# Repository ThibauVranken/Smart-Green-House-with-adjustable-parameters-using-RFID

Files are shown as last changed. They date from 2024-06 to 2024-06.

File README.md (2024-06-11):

# Smart-Green-House-with-adjustable-parameters-using-RFID

In this project, you will see how to make your own smart greenhouse with customisable parameters using RFID. The measured sensor values are nicely displayed in a Grafana dashboard via a Grafana server.  You can use this in the industry, for example, to reduce costs in terms of actuator energy or to get a better picture of the situation your plants are in. This way, the plants will always have the ideal environment so they grow faster and healthier.

Folder ‘Documentation + tutorial’:
All hardware and software are in the document ‘Documentatie Serre’ and the explanation to set up a Grafana server is in the document ‘Grafana server’.

Folder ‘Code’:
The code for the ESP32 and the RaspberryPi (MQTT - InfluxDB bridge) are both in this folder.

Folder ‘PCB’:
Here you will find the electronic schematic and pcb design. For more explanation of the circuits, please see ‘Documentatie Serre’.

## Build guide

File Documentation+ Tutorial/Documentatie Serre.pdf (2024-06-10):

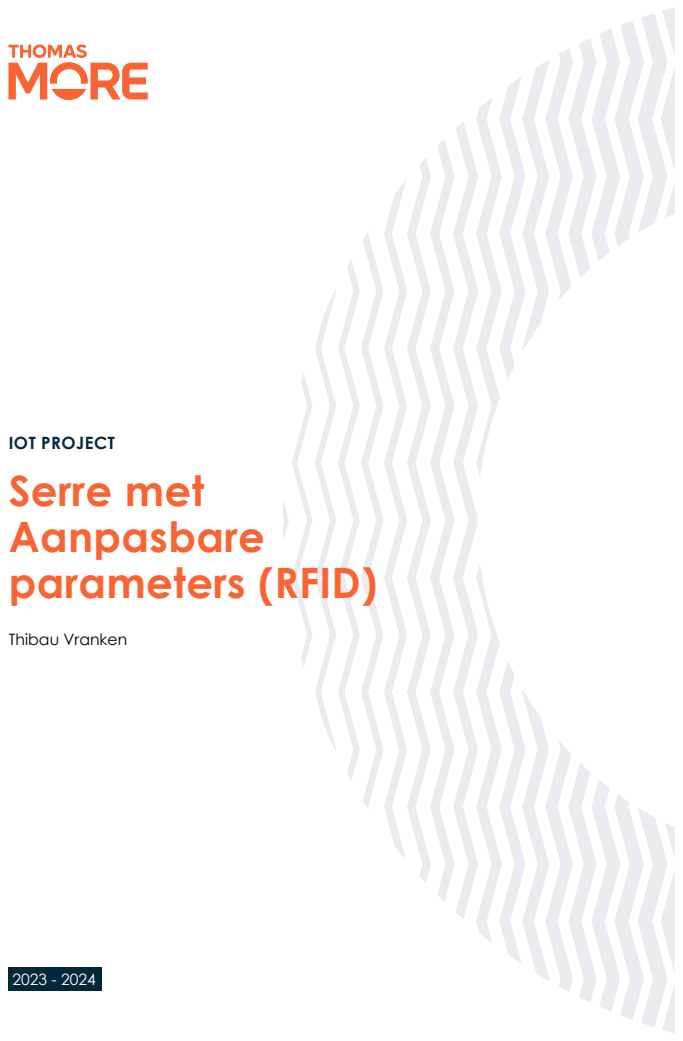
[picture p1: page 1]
IoT project Thibau Vranken; IOT PROJECT Serre met Aanpasbare parameters (RFID); Thibau Vranken

Dit is de koptekst in stijl ‘Koptekst’

# Inhoud

### 1. PROJECTBESCHRIJVING ____________________________________________________________4

### 2. HARDWARE _______________________________________________________________________5

2.1. Microcontrollers _________________________________________________________________5
2.1.1. ESP32 _____________________________________________________________________5
2.1.2. RaspberryPi 4B ______________________________________________________________5
2.2. PCB Hardware __________________________________________________________________6
2.2.1. 2x 5V relay’s_________________________________________________________________6
2.2.2. 3x PC817 optocouplers ________________________________________________________6
2.2.3. 5x BC547B transistors _________________________________________________________6
2.2.4. Schroefterminals _____________________________________________________________7
2.2.5. 5x rode Feedback LED_________________________________________________________7
2.2.6. Weerstanden ________________________________________________________________8
2.2.7. Pinheaders __________________________________________________________________8
2.3. Sensors en Modules ______________________________________________________________9
2.3.1. DHT11 _____________________________________________________________________9
2.3.2. LDR module _________________________________________________________________9
2.3.3. Bodemvochtigheidssensor ______________________________________________________9
2.3.4. DS18B20 sensor ____________________________________________________________10
2.3.5. RFID module _______________________________________________________________10
2.3.6. HC SR04 Ultrasone sensor ____________________________________________________ 11
2.4. Actuatoren ____________________________________________________________________ 11
2.4.1. 2x 12V ventilatoren___________________________________________________________ 11
2.4.2. Waterpompje _______________________________________________________________12
2.4.3. Oude soldeerbout____________________________________________________________12
2.4.4. Lamp _____________________________________________________________________12
2.4.5. Oude visbak (Serre) __________________________________________________________13

### 3. PCB _____________________________________________________________________________13

3.1. Schema_______________________________________________________________________13
3.1.1. Verbindingen sensors_________________________________________________________14
3.1.2. Schakelingen Actuatoren ______________________________________________________14
3.2. PCB design____________________________________________________________________16

### 4. CODE____________________________________________________________________________17

4.1. Code ESP32 ___________________________________________________________________17
4.1.1. Volledige code ______________________________________________________________17
4.1.2. Code uitgelegd ______________________________________________________________17
4.2. Code RaspberryPi ______________________________________________________________29
4.2.1. Volledige code ______________________________________________________________29
4.2.2. Code Uitgelegd______________________________________________________________29

### 5. GRAFANA SERVER ________________________________________________________________33

5.1. MQTT communicatie_____________________________________________________________33
5.1.1. Mosquitto installeren _________________________________________________________33

5.1.2. Configuratie bestand aanpassen ________________________________________________33
5.1.3. Code maken en kijken of de communicatie goed gebeurt _____________________________33
5.2. Server Setup___________________________________________________________________34
5.2.1. Installeer InfluxDB ___________________________________________________________34
5.2.2. Maak een database aan_______________________________________________________34
5.2.3. Controleer of de data aankomt in de database _____________________________________35
5.3. InfluxDB connecteren met Grafana voor visualisatie ____________________________________35
5.3.1. Zoek je Grafana server________________________________________________________35
5.3.2. Log in in Grafana ____________________________________________________________35
5.3.3. Maak een connectie met je InfluxDB database _____________________________________36
5.4. Data Visualisatie ________________________________________________________________38

### 6. DATASHEETS _____________________________________________________________________38

6.1. ESP 32 _______________________________________________________________________38
6.2. RaspberryPi ___________________________________________________________________38
6.3. BC547B Transistor ______________________________________________________________38
6.4. PC 817 optocoupler _____________________________________________________________38
6.5. 5V relay_______________________________________________________________________39
6.6. Feedback LED’s ________________________________________________________________39

# 1. Projectbeschrijving

Het project is een slimme serre die zichzelf regelt qua omgevingstemperatuur, bodem- en luchtvochtigheid en licht.

Deze waarden worden gemonitord (actuatoren worden op het juiste moment aangestuurd) door een ESP32 die de waarden doorstuurt naar een RaspberryPi waarna deze de waarden doorstuurt naar de InfluxDB database zodat we op Grafana een mooi overzicht krijgen van de geschiedenis van de waarden.

We kunnen de parameters voor alle gegevens aanpassen door RFID tags te scannen die elk vaste parameters hebben. Bijvoorbeeld: Als we de blauwe RFID tag scannen wordt de maximum temperatuur gezet op 25°C (als de temperatuur hoger is dan 25°C dan wordt er aan ventilator aangestuurd), als we dan de witte tag scannen wordt de maximale temperatuur gezet op bijvoorbeeld 20°C (zo gaat de ventilator sneller aan om de temperatuur onder 20°C te houden).

# 2. Hardware

### 2.1. Microcontrollers

### 2.1.1. ESP32

De ESP32 regelt de hele serre. Het meet de temperatuur van de omgeving en bodem, het meet de lucht-en bodemvochtigheid, of er veel licht is in de omgeving en hoeveel water in het waterreservoir zit (alle sensoren hiervoor worden vermeldt in ‘Sensors en Actuatoren’). Het houdt ook rekening met welke RFID tag voor het laatst gescand geweest is zodat alles op het juiste moment wordt aangestuurd.

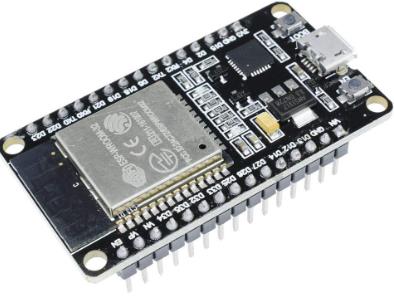
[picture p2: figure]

### 2.1.2. RaspberryPi 4B

De RaspberryPi ontvangt alle waarden van de ESP32 via MQTT en stuurt deze naar de InfluxDB Database. Hierdoor kunnen we mooi en overzichtelijk de geschiedenis van de waarden zien.

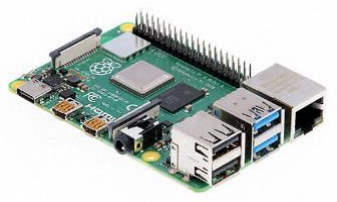
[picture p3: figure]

### 2.2. PCB Hardware

2.2.1. 2x 5V relay’s

Deze zorgen ervoor dat je hoge voltages kan schakelen (240V). Dit is handig voor de lamp (als het te donker is) en de verwarming (als het te koud is).

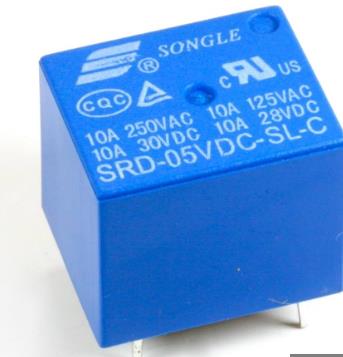
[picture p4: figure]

2.2.2. 3x PC817 optocouplers

Met de PC817 kan je veilig schakelingen galvanisch scheiden doordat het een transistor is met een lichgevoelige basis. De LED die de basis van de transistor moet schakelen wordt gecontroleerd door de ESP32. Op deze manier blijven de stroomkringen van de actuatoren en de ESP32 mooi gescheiden. (Voor toepassing, zie Schakelingen Actuatoren, Lage Voltages)

2.2.3. 5x BC547B transistors

Om de relay en de PC817 te kunnen schakelen heb ik de BC547B transistor gebruikt. Ze worden wel anders gebruikt naargelang de voltage die geschakeld moet worden (zie Schakelingen Actuatoren).

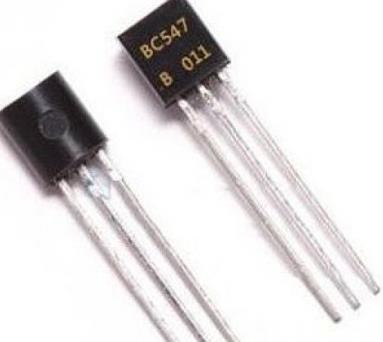
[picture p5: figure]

### 2.2.4. Schroefterminals

2.2.4.1. 2 Schroefterminals

Om de actuatoren en de voedingen voor de actuatoren niet definitief te monteren aan het PCB heb ik 10 keer 2 schroefterminals gebruikt. Zo kun je ook makkelijk veranderingen doen aan de voedingen/actuatoren.

2.2.4.2. 3 Schroefterminal

Om de DS18B20 sensor (niet definitief) te kunnen monteren heb ik een 3 schroefterminal gebruikt.

2.2.5. 5x rode Feedback LED

Om duidelijk te kunnen zien welke actuatoren aan zijn (welke schakeling geschakeld is), heb ik in elke schakeling een rode feedback LED geplaatst zodat je aan de LED kunt zien wat ‘aan’ is en wat ‘uit’ is.

### 2.2.6. Weerstanden

Weerstanden heb ik gebruikt om de juiste stroom/voltage vereisten te krijgen voor elke schakeling (zie PCB Design voor juiste waarden).

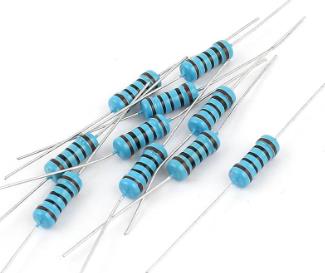
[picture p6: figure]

### 2.2.7. Pinheaders

### 2.2.7.1. Male headers

Om de sensoren te kunnen verbinden met het PCB heb ik male headers gebruikt om zo via jumpercables de sensor op de juiste plaats te krijgen.

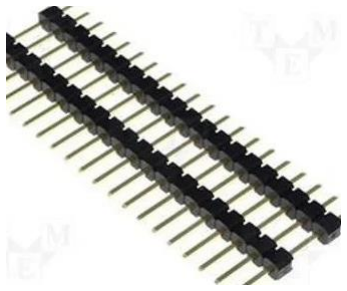
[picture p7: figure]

### 2.2.7.2. Female Headers

Om modules snel te kunnen vervangen en niet definitief aan het PCB te moeten hangen heb ik female headers gebruikt.

### 2.3. Sensors en Modules

### 2.3.1. DHT11

Om de omgevingstemperatuur en luchtvochtigheid te kunnen meten en monitoren heb ik de DHT11 sensor gebruikt.

### 2.3.2. LDR module

Om het licht in de omgeving te meten heb ik de LDR module gebruikt.

### 2.3.3. Bodemvochtigheidssensor

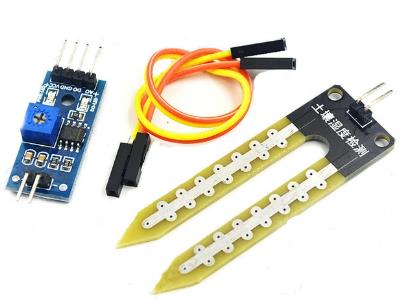
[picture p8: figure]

Om de bodemvochtigheid te kunnen meten heb ik deze bodemvochtigheidssensor gebruikt.

### 2.3.4. DS18B20 sensor

Met de DS18B20 sensor kan ik de bodemtemperatuur meten.

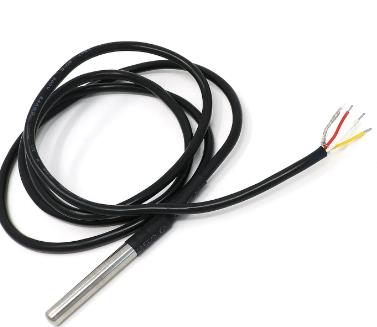
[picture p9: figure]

### 2.3.5. RFID module

Om de parameters aan te kunnen passen naargelang het gewas/plant er in de serre staat kan je je RFID tags scannen op de RFID module. Elke tag heeft vaste vooraf ingestelde parameters (je kan deze aanpassen in je code). Zo kun je snel en makkelijk het systeem van je serre veranderen.

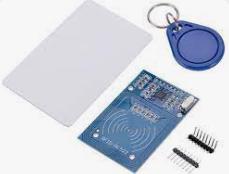
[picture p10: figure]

### 2.3.6. HC SR04 Ultrasone sensor

De HC SR04 sensor kan zeer gedetailleerd afstanden meten. Ik heb deze boven het wateroppervlak van het waterreservoir geplaatst zodat je de inhoud van het waterreservoir kan meten en monitoren.

### 2.4. Actuatoren

2.4.1. 2x 12V ventilatoren

Om de luchtvochtigheid en temperatuur te regelen van de serre heb ik 2 ventilatoren gebruikt. Beide heb ik ze in het plafond van de serre geplaatst. De ene ventilator heb ik zo gemonteerd zodat deze lucht in de serre blaast voor als het te warm is, en de andere heb ik zo gemonteerd zodat deze lucht uit de serre haalt zodat de lucht kan opdrogen voor als deze te nat is.

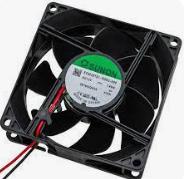
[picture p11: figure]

### 2.4.2. Waterpompje

Om water te kunnen geven aan de planten als de bodem te droog is, heb je natuurlijk een waterpompje nodig. Ik heb daarvoor deze gebruikt:

### 2.4.3. Oude soldeerbout

Als verwarmingselement heb ik een oude soldeerbout gebruikt die ik nog thuis had liggen. Deze heb ik ook door het plafond naar binnen gehangen zodat de warmte mooi verdeeld word in de serre.

### 2.4.4. Lamp

Als het te donker is moet er natuurlijk licht gemaakt worden. Hiervoor heb ik een gewone lamp gebruikt.

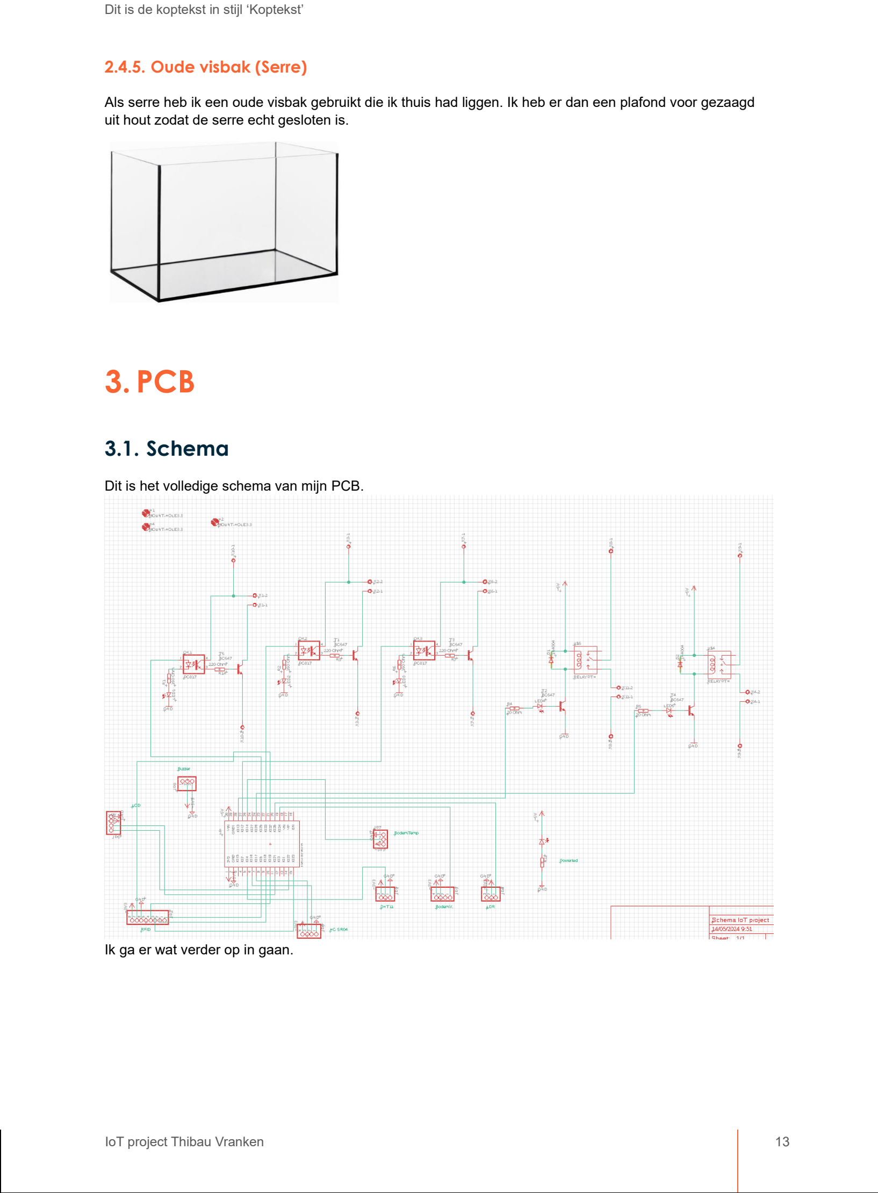
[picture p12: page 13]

### 2.4.5. Oude visbak (Serre)

Als serre heb ik een oude visbak gebruikt die ik thuis had liggen. Ik heb er dan een plafond voor gezaagd uit hout zodat de serre echt gesloten is.

# 3. PCB

### 3.1. Schema

Dit is het volledige schema van mijn PCB.

Ik ga er wat verder op in gaan.

### 3.1.1. Verbindingen sensors

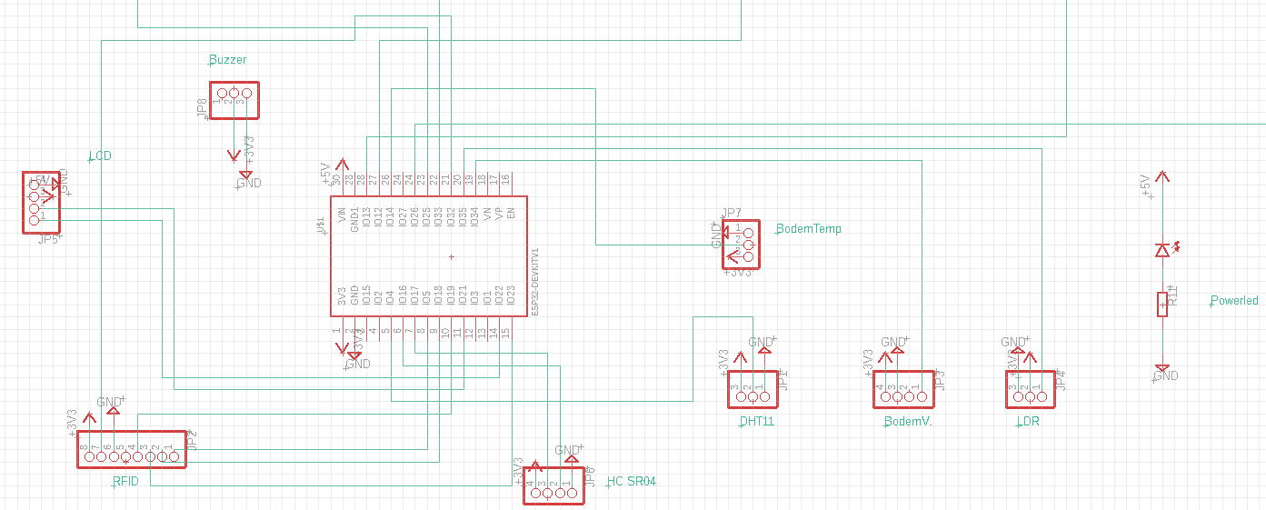
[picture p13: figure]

Op deze foto zie je de verbindingen die ik gemaakt heb met de sensors en de ESP32. Over het algemeen is er niets speciaal hier. Alle sensoren zijn verbonden met de 3,3V power supply van de ESP32 en zijn dan ook verbonden met de pinnen die hun zijn toegewezen (zie Code). Rechts op de foto zie je een LED staan, deze is enkel ter controle of er wel spanning staat op de relay’s en de transistoren (zie Schakelingen Actuatoren).

### 3.1.2. Schakelingen Actuatoren

### 3.1.2.1. Lage voltages (Max 45V (zie datasheet BC547B transistor))

Om lage voltages te schakelen heb ik dus gekozen voor een schakeling met de BC547B transistor en de PC817 optocoupler. Deze gaan (normaal gezien) langer mee dan standaard relay’s maar kunnen dus geen hoge voltages schakelen.
Uitleg schakeling:
Om de PC817 te activeren (dus de fototransistor laten geleiden) moet de bepaalde pin van de ESP32 (zie Code) ‘Hoog’ staan. Zo vlooit er stroom door de LED in de PC817, wordt de transistor geactiveerd en is het circuit open. (Na de LED van de PC817 heb ik zelf nog een rode LED geplaatst om te zien of de schakeling weldegelijk geschakeld is.) Aan de andere kant (kant van fototransistor) vlooit de stroom van de actuator, door dat de foto transistor ‘aan’ staat. Bij de aansluitingen boven en onder aan elke schakeling worden respectievelijk de positieve en de negatieve polen van de voeding aangesloten. Bij de aansluitingen in het midden van elke schakeling worden dan, ook van boven naar onder, de positieve en de negatieve kant van de actuator aangesloten. Deze schakelingen gelden dus enkel voor actuatoren die minder dan 45V nodig hebben!

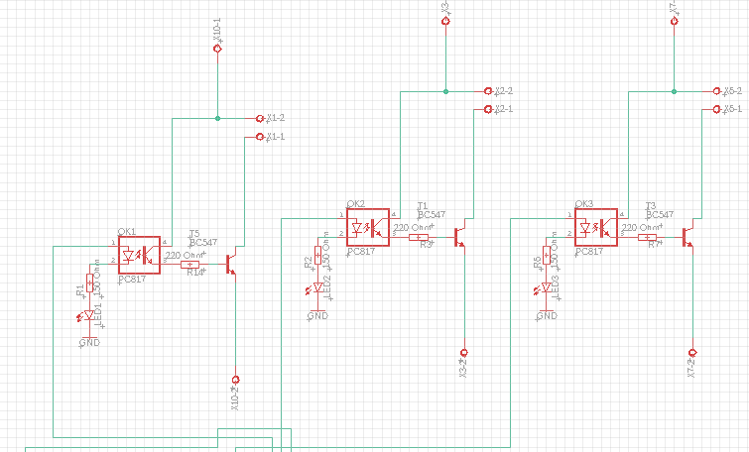
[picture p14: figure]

### 3.1.2.2. Hoge voltages (Max 240V AC)

Om de hoge voltages te kunnen schakelen heb ik dus standaard relay’s gebruikt. Deze gaan over het algemeen minder lang mee dan transistoren en optocouplers maar kunnen dus wel grote voltages (AC en DC) schakelen. Nog een nadeel is dat ze best wel wat plek innemen op je PCB.
Uitleg Schakeling:
Bij deze schakeling zorgt de BC547B transistor voor de schakeling van de relay (anders dan in de vorige schakeling). De BC547B transistor heb ik geplaatst zodat deze de stroomgang van de 5V kant van de relay kan controleren. Als de bepaalde pin van de ESP32 (zie Code) ‘hoog’ staat dan gaat deze op de basis van de transistor en begint deze te geleiden waardoor de relay schakelt. Ook hier heb ik een LED geplaatst zodat je kan zien of de schakeling ‘aan’ staat (hier op de basis van de transistor). De diode die ik heb geplaatst over de spoel van de relay is een flyback diode, hierdoor wordt de spanningspiek geëlimineerd als de relay ‘uit’ gaat. De voeding sluit je ook hier aan zoals bij de ander schakelingen, positieve kant
bovenaan, negatieve kant onderaan. De actuatoren zij verbonden met de NO pin van de relay (Normally Open) zodat deze alleen werken als de relay geschakeld is. De actuatoren sluit je hier ook aan de middelste terminals aan, bovenste positief, onderste negatief.

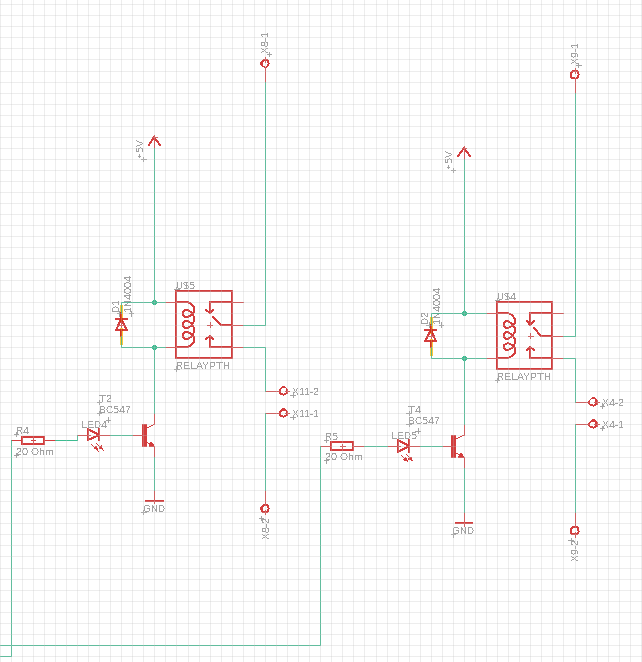
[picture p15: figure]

### 3.2. PCB design

Hier is het PCB design van het schema:

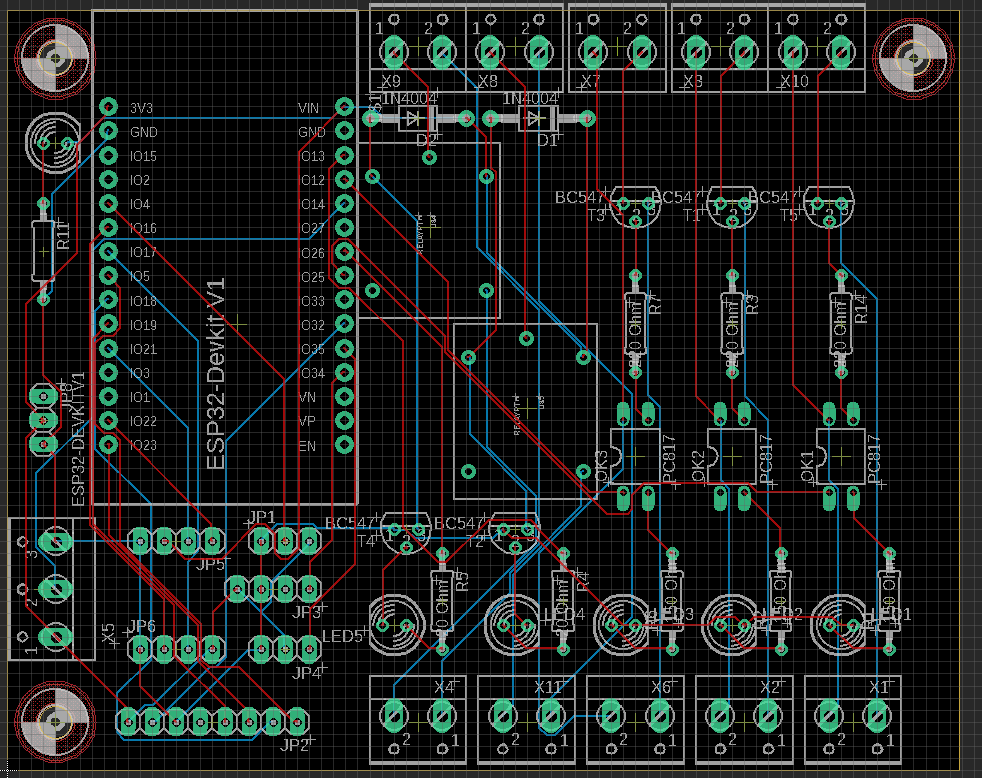
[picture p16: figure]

De ESP32, de RFID module en de buzzer sluit ik aan aan de printplaat via de ‘female pinheaders’ zodat je ze gemakkelijk kan veranderen/afhalen voor ander project.
De sensors en LCD verbindt ik via female-female jumpercables zodat ik ze op de plaatst kan leggen waar ze moeten liggen/hangen.
Zorg ervoor dat je de aansluitingen van de actuatoren en voedingen aan de zijkant zet zodat je er gemakkelijk aan kunt.
(Wegens een fout in de library van de ESP32 kon ik GPIO 27 niet gebruiken in mijn schema, daarom zou ik deze lijn zelf nog moeten leggen met een kabeltje.

# 4. Code

### 4.1. Code ESP32

### 4.1.1. Volledige code

Om de volledige code te zien, zie dan bestand ‘Serre.ino’.

### 4.1.2. Code uitgelegd

Deze code doet eigenlijk bijna alles. Het meet sensorwaarden, het kijkt wanneer er een RFID tag gelezen moet worden, wanneer de parameters moeten worden aangepast, regelt het LCD scherm en stuurt al de sensorwaarden door naar de broker.

### 4.1.2.1. Libraries

#include "DHT.h" | // Library for DHT sensors

#include <WiFi.h> | // Library for WiFi functionality

#include <PubSubClient.h> | // Library for MQTT functionality

#include "LiquidCrystal_I2C.h" | // Library for I2C LCD

#include "Wire.h" | // Library for I2C communication

#include <WiFiClientSecure.h> | // Library for secure WiFi client

#include <MFRC522.h> | // Library for RFID functionality

#include <afstandssensor.h> | // Custom library for distance sensor

#include <UniversalTelegramBot.h> | // Library for Telegram bot

#include <ArduinoJson.h> | // Library for JSON parsing

#include <SPI.h> | // Library for SPI communication

#include <OneWire.h> | // Library for 1-Wire communication

#include <DallasTemperature.h> | // Library for Dallas Temperature

sensors
#include <Preferences.h> | // Library for storing preferences

### 4.1.2.2. DHT type vastzetten, pinnen voor sensoren, actuatoren

//Pinnen voor actuatoren en sensoren
//DHT type vastzetten
#define VentilTemp 25

#define VentilHum 33

#define Pomp 12

#define Verwarming 13

#define Lamp 26

#define ldrPin 35

#define bvPin 34

#define btPin 14

#define RST_PIN 32

#define SS_PIN 5

#define DHTPIN 4

#define DHTTYPE DHT11

### 4.1.2.3. Wifi/MQTT Instanties en Chatbot definiëren

#define CHAT_ID "..."

#define BOTtoken "..."

WiFiClientSecure client;
WiFiClient espClient;
PubSubClient mqttClient(espClient); Preferences preferences;

### 4.1.2.4. WiFi en MQTT credentials

//WiFi credentials
const char* ssid = "...";
const char* password = "..."; //MQTT credentials
const char* mqtt_server = "..."; const int mqtt_port = 1883;
const char* MQTT_USER = "...";
const char* MQTT_PASSWORD = "...";
const char* MQTT_CLIENT_ID = "MQTTclient";

### 4.1.2.5. MQTT topics aanmaken voor alle waarden

//MQTT topics aanmaken voor elke waarde
//Waarden
const char* MQTT_TOPICtemp = "serre/waarden/temperature"; const char* MQTT_TOPIChum = "serre/waarden/humidity"; const char* MQTT_TOPIClight = "serre/waarden/light"; const char* MQTT_TOPICbv = "serre/waarden/bodemvocht"; const char* MQTT_TOPICbt = "serre/waarden/bodemtemp";
const char* MQTT_TOPICWater = "serre/waarden/waterres";
//Actuatoren
const char* MQTT_TOPICVentilTempTijd = "serre/actuatoren/VentilTempDraaitijd"; const char* MQTT_TOPICVentilHumTijd = "serre/actuatoren/VentilHumDraaitijd"; const char* MQTT_TOPICPompTijd = "serre/actuatoren/PompDraaitijd";
const char* MQTT_TOPICLichtTijd = "serre/actuatoren/LampDraaitijd";
const char* MQTT_TOPICVerwTijd = "serre/actuatoren/VerwDraaitijd"; //Parameters
const char* MQTT_TOPICParameterMaxTemp = "serre/parameters/MaxTemp"; const char* MQTT_TOPICParameterMinTemp = "serre/parameters/MinTemp"; const char* MQTT_TOPICParameterMaxHum = "serre/parameters/MaxHum"; const char* MQTT_TOPICParameterMinLight = "serre/parameters/MinLight";

const char* MQTT_TOPICParameterMinBv = "serre/parameters/MinBv";

const char* MQTT_TOPICCommunication = "serre/communication/communication"; const char* MQTT_REGEX = "serre/([^/]+)/([^/]+)";

### 4.1.2.6. Alle instanties aanmaken

LiquidCrystal_I2C lcd(0x27, 16, 4); DHT dht(DHTPIN, DHTTYPE);
OneWire oneWire(btPin);
DallasTemperature sensors(&oneWire); AfstandsSensor afstandssensor(17, 16); UniversalTelegramBot bot(BOTtoken, client); MFRC522 mfrc522(SS_PIN, RST_PIN);

### 4.1.2.7. Variabelen en constanten definiëren

unsigned long lastDisplayUpdateTime = 0;
const unsigned long displayUpdateInterval = 5000; // Interval van 5 seconden voor het bijwerken van het display
const unsigned long waterUpdateInterval = 10000;
unsigned long lastWaardenUpdateTime = 0;
const unsigned long waardenUpdateInterval = 10000; // Interval van 5 seconden voor het bijwerken van het display
unsigned long lastParametersUpdateTime = 0;
const unsigned long parametersUpdateInterval = 10000;
unsigned long lastActuatorsUpdateTime = 0;
const unsigned long actuatorsUpdateInterval = 3000; unsigned long lastCommunicationUpdateTime = 0;
const unsigned long communicationUpdateInterval = 5000; int botRequestDelay = 1000;
unsigned long lastTimeBotRan;
bool newRFIDScan = false;
bool displaySensorValues = true;

### 4.1.2.8. Standaad waarden voor parameters instellen en float maken voor

waterreservoir te meten

int maxTemp = 24; | // Maximale temperatuur standaard instelling
int minTemp = 18; | // Minimale temperatuur standaard instelling
int maxHum = 60; | // Maximale luchtvochtigheid standaard instelling
int minLight = 50; | // Minimale lichtintensiteit standaard instelling
int minBodemvocht = 30; // Minimale bodemvochtigheid standaard instelling float water;
TaskHandle_t Task1;

### 4.1.2.9. Functie om te verbinden met WiFi

void setup_wifi() {
delay(10);
Serial.println();
Serial.print("Verbinding maken met WiFi..."); WiFi.begin(ssid, password);
while (WiFi.status() != WL_CONNECTED) { delay(500);
Serial.print(".");
}
Serial.println("");
Serial.println("WiFi verbonden"); Serial.println("IP adres: "); Serial.println(WiFi.localIP());
}

### 4.1.2.10. Functie om te verbinden met MQTT broker

void reconnect() {
while (!mqttClient.connected()) { Serial.print("Verbinding maken met MQTT-broker..."); lcd.clear();
lcd.setCursor(0, 0);
lcd.print("Verbinden met");
lcd.setCursor(0, 1);
lcd.print("MQTT broker...");
if (mqttClient.connect(MQTT_CLIENT_ID, MQTT_USER, MQTT_PASSWORD)) { Serial.println(" verbonden"); mqttClient.subscribe(MQTT_TOPICCommunication);

} else {
Serial.print(" mislukt, rc="); Serial.print(mqttClient.state()); Serial.println(" opnieuw proberen in 5 seconden"); delay(5000);
}
}
}

### 4.1.2.11. Functie die de sensorwaarden leest, de sensorwaarden en de parameters

verstuurd via MQTT en het LCD scherm regelt

void clientPubTask(void* pvParameters) {
while (true) {
if (!mqttClient.connected()) { reconnect();

}
sensors.requestTemperatures();
float h = dht.readHumidity();
float t = dht.readTemperature();
float l = map(analogRead(ldrPin), 0, 4096, 100, 0); float b = map(analogRead(bvPin), 0, 4096, 100, 0); float bt = sensors.getTempCByIndex(0);

unsigned long currentTime1 = millis();
if (currentTime1 - lastActuatorsUpdateTime >= actuatorsUpdateInterval) { if (t >= maxTemp) {
digitalWrite(VentilTemp, HIGH);
digitalWrite(Verwarming, LOW); mqttClient.publish(MQTT_TOPICVentilTempTijd, static_cast<const char*>("1"));
mqttClient.publish(MQTT_TOPICVerwTijd, static_cast<const char*>("0")); } else if (t >= minTemp && t < maxTemp) {
digitalWrite(VentilTemp, LOW);
digitalWrite(Verwarming, LOW); mqttClient.publish(MQTT_TOPICVentilTempTijd, static_cast<const char*>("0"));
mqttClient.publish(MQTT_TOPICVerwTijd, static_cast<const char*>("0"));

} else if (t < minTemp) {
digitalWrite(Verwarming, HIGH);
digitalWrite(VentilTemp, LOW); mqttClient.publish(MQTT_TOPICVerwTijd, static_cast<const char*>("1")); mqttClient.publish(MQTT_TOPICVentilTempTijd, static_cast<const char*>("0"));
}
if (h >= maxHum) {
digitalWrite(VentilHum, HIGH); mqttClient.publish(MQTT_TOPICVentilHumTijd, static_cast<const char*>("1"));
} else {
digitalWrite(VentilHum, LOW); mqttClient.publish(MQTT_TOPICVentilHumTijd, static_cast<const char*>("0"));
}
if (l <= minLight) {
digitalWrite(Lamp, HIGH);
mqttClient.publish(MQTT_TOPICLichtTijd, static_cast<const char*>("1"));
} else {
digitalWrite(Lamp, LOW);
mqttClient.publish(MQTT_TOPICLichtTijd, static_cast<const char*>("0"));

}
if (b <= minBodemvocht) {
digitalWrite(Pomp, HIGH);
mqttClient.publish(MQTT_TOPICPompTijd, static_cast<const char*>("1")); } else {
digitalWrite(Pomp, LOW);
mqttClient.publish(MQTT_TOPICPompTijd, static_cast<const char*>("0")); }
Serial.println("status verzonden");
lastActuatorsUpdateTime = currentTime1;
}
unsigned long currentTime2 = millis();
if (currentTime2 - lastWaardenUpdateTime >= waardenUpdateInterval) { String ts = String(t);
String hs = String(h);
String ls = String(l);
String bs = String(b);
String bts = String(bt);
mqttClient.publish(MQTT_TOPICtemp, ts.c_str()); mqttClient.publish(MQTT_TOPIChum, hs.c_str()); mqttClient.publish(MQTT_TOPIClight, ls.c_str()); mqttClient.publish(MQTT_TOPICbv, bs.c_str()); mqttClient.publish(MQTT_TOPICbt, bts.c_str()); //Serial.println("waarden verzonden"); lastWaardenUpdateTime = currentTime2;
}

unsigned long currentTime3 = millis();
if (currentTime3 - lastParametersUpdateTime >= parametersUpdateInterval) { sendParameters();
lastParametersUpdateTime = currentTime3;
}

if (displaySensorValues) { lcd.setCursor(0, 0);
lcd.print("Omgevingsinfo:"); lcd.setCursor(0, 1);
lcd.print("Temp.:");
lcd.print(t);
lcd.print(" C");
lcd.setCursor(-4, 2);
lcd.print("Hum. :");
lcd.print(h);
lcd.print("%");
lcd.setCursor(-4, 3);
lcd.print("Licht:");
lcd.print(l);

lcd.print("%");
} else {
lcd.setCursor(0, 0);
lcd.print("Bodeminfo:");
lcd.setCursor(0, 1);
lcd.print("BodemV.:");
lcd.print(b);
lcd.print("%");
lcd.setCursor(-4, 2);
lcd.print("BodemT.:");
lcd.print(bt);
lcd.print(" C");
lcd.setCursor(-4, 3);
}

unsigned long currentTime4 = millis();
if (currentTime4 - lastDisplayUpdateTime >= displayUpdateInterval) { lastDisplayUpdateTime = currentTime4;
displaySensorValues = !displaySensorValues;
lcd.clear();
}

if (newRFIDScan) {
lcd.clear();
lcd.setCursor(0, 0);
lcd.print("New Parameters "); lcd.setCursor(0, 1);
lcd.print("MaxTemp = ");
lcd.print(maxTemp);
lcd.print(" C");
lcd.setCursor(-4, 2);
lcd.print("MinTemp = ");
lcd.print(minTemp);
lcd.print(" C");
lcd.setCursor(-4, 3);
lcd.print("MaxHum = ");
lcd.print(maxHum);
lcd.print(" %");
delay(5000);
lcd.clear();
lcd.setCursor(0, 0);
lcd.print("New Parameters "); lcd.setCursor(0, 1);
lcd.print("MinLicht = ");
lcd.print(minLight);
lcd.print("%");
lcd.setCursor(-4, 2);

lcd.print("MinBodemV. = "); lcd.print(minBodemvocht);
lcd.print("%");
delay(5000);
newRFIDScan = false; // Reset de nieuwe RFID-scan status }
}
}

### 4.1.2.12. Functie die wordt aangeroepen als de ESP32 een MQTT bericht ontvangt

void callback(char* topic, byte* payload, unsigned int length) {
unsigned long currentTime1 = millis();
if (currentTime1 - lastCommunicationUpdateTime >= communicationUpdateInterval) {
Serial.print("Message arrived ["); Serial.print(topic);
Serial.print("] ");
Serial.print("Message: ");
String bericht;
for (int i = 0; i < length; i++) {
bericht += ((char)payload[i]);
}
if (String(topic) == MQTT_TOPICCommunication) { if (bericht == "hallo") {
Serial.println(bericht);
}
}
lastCommunicationUpdateTime = currentTime1; }
}

### 4.1.2.13. Setup functie

void setup() {
Serial.begin(9600);
pinMode(25, OUTPUT);
pinMode(33, OUTPUT);
pinMode(12, OUTPUT);
pinMode(13, OUTPUT);
pinMode(26, OUTPUT);
pinMode(27, OUTPUT);
pinMode(ldrPin, INPUT);
pinMode(bvPin, INPUT);
pinMode(btPin, INPUT);

dht.begin();
setup_wifi();
mqttClient.setServer(mqtt_server, mqtt_port); mqttClient.setCallback(callback); reconnect();

lcd.init();
lcd.backlight();
Wire.begin(SDA, SCL);
SPI.begin();
mfrc522.PCD_Init();
sensors.begin();
client.setCACert(TELEGRAM_CERTIFICATE_ROOT);

preferences.begin("serre", false); // Beginnen met de voorkeuren met de naam "serre"
// Lezen van opgeslagen waarden of standaardwaarden gebruiken als er geen opgeslagen waarden zijn
maxTemp = preferences.getInt("maxTemp", 24);
minTemp = preferences.getInt("minTemp", 18);
maxHum = preferences.getInt("maxHum", 60);
minLight = preferences.getInt("minLight", 50); minBodemvocht = preferences.getInt("minBodemvocht", 30);

lcd.clear();
lcd.setCursor(0, 0);
lcd.print("Verbonden met"); lcd.setCursor(0, 1);
lcd.print("MQTT broker");
delay(3000);
lcd.clear();
lcd.setCursor(0, 0);
lcd.print("Used Parameters "); lcd.setCursor(0, 1);
lcd.print("MaxTemp = ");
lcd.print(maxTemp);
lcd.print(" C");
lcd.setCursor(-4, 2);
lcd.print("MinTemp = ");
lcd.print(minTemp);
lcd.print(" C");
lcd.setCursor(-4, 3);
lcd.print("MaxHum = ");
lcd.print(maxHum);
lcd.print(" %");
delay(5000);
lcd.clear();

lcd.setCursor(0, 0);
lcd.print("Used Parameters "); lcd.setCursor(0, 1);
lcd.print("MinLicht = ");
lcd.print(minLight);
lcd.print("%");
lcd.setCursor(-4, 2);
lcd.print("MinBodemV. = "); lcd.print(minBodemvocht);
lcd.print("%");
delay(5000);

xTaskCreatePinnedToCore(
clientPubTask,
"clientPubTask",
10000,
NULL,
1,
NULL,
0);
}

### 4.1.2.14. Functie die de RFID tags leest

void RFIDtagLezen() {
static String Tag = ""; // Variabele om de vorige RFID-tag op te slaan if (!mfrc522.PICC_IsNewCardPresent()) {
return;
}
// Select one of the cards
if (!mfrc522.PICC_ReadCardSerial()) { return;
}
Serial.print("UID tag :");
String content = "";
for (byte i = 0; i < mfrc522.uid.size; i++) { Serial.print(mfrc522.uid.uidByte[i] < 0x10 ? " 0" : " "); Serial.print(mfrc522.uid.uidByte[i], HEX); content.concat(String(mfrc522.uid.uidByte[i] < 0x10 ? "0" : "")); content.concat(String(mfrc522.uid.uidByte[i], HEX));
}
Serial.println();
Serial.print("Message : ");
content.toUpperCase();
Serial.println(content.substring(1));

Tag = content.substring(1);

if (Tag == "...") {
// Parameters voor blauwe RFID-tag maxTemp = 26;
minTemp = 20;
maxHum = 75;
minLight = 60;
minBodemvocht = 35;
} else if (Tag == "...") {
// Parameters voor witte RFID-tag maxTemp = 22;
minTemp = 16;
maxHum = 65;
minLight = 40;
minBodemvocht = 30;
}
/* Nieuwe parameters direct opslaan zodat
deze opnieuw worden a-ingesteld als de ESP reset*/ preferences.putInt("maxTemp", maxTemp); preferences.putInt("minTemp", minTemp); preferences.putInt("maxHum", maxHum); preferences.putInt("minLight", minLight); preferences.putInt("minBodemvocht", minBodemvocht); sendParameters();
newRFIDScan = true;
tone(27, 1000);
delay(1000);
noTone(27);
}
4.1.2.15. 3 functies om de Telegram chatbot te laten werken

String getWater() {
water = afstandssensor.afstandCM(); Serial.print("Afstand: ");
Serial.print(water);
Serial.println("cm");
String message = "Afstand: " + String(water) + "cm \n"; return message;
bot.sendMessage(CHAT_ID, message, "");
}

void handleNewMessages(int numNewMessages) { Serial.println("handleNewMessages"); Serial.println(String(numNewMessages));
for (int i = 0; i < numNewMessages; i++) {
String chat_id = String(bot.messages[i].chat_id);

if (chat_id != CHAT_ID) {
bot.sendMessage(chat_id, "Unauthorized user", ""); continue;
}
String text = bot.messages[i].text; Serial.println(text);
String from_name = bot.messages[i].from_name;
if (text == "/start") {
String welcome = "Welcome, " + from_name + ".\n";
welcome += "Use the following command to get current readings.\n\n"; welcome += "/readings \n";
bot.sendMessage(chat_id, welcome, "");
}
if (text == "/readings") {
String readings = getWater(); bot.sendMessage(chat_id, readings, ""); }
}
}

void waterReservoir() {
static unsigned long lastWaterUpdate = 0;
unsigned long currentTime = millis();
// Controleer of er 10 seconden verstreken zijn sinds de laatste keer dat de waarde 'water' is verzonden
if (currentTime - lastWaterUpdate >= waterUpdateInterval) {
float water = afstandssensor.afstandCM();
// Verstuur de waarde 'water' als deze meer dan 10 cm is if (water > 5 && water < 400) {
String waters = String(water); Serial.println(water);
mqttClient.publish(MQTT_TOPICWater, waters.c_str()); lastWaterUpdate = currentTime;
/* Stuurt een waarschuwingsbericht als het
waterreservoir bijna leeg is*/
if (water < 10) {
String alertMessage = "Waarschuwing: Waterreservoir is bijna leeg!"; bot.sendMessage(CHAT_ID, alertMessage, "");
lastWaterUpdate = currentTime; // Update de tijd van de laatste verzending
}
// Handel de bot-updates af zoals eerder
if (millis() > lastTimeBotRan + botRequestDelay) {
int numNewMessages = bot.getUpdates(bot.last_message_received + 1); while (numNewMessages) {
Serial.println("got response"); handleNewMessages(numNewMessages);

numNewMessages = bot.getUpdates(bot.last_message_received + 1); }
lastTimeBotRan = millis();
}
}
}
}

### 4.1.2.16. Functie om parameters te versturen

void sendParameters() {
String maxTemps = String(maxTemp); String minTemps = String(minTemp);
String maxHums = String(maxHum);
String minLights = String(minLight);
String minBodemvochts = String(minBodemvocht); mqttClient.publish(MQTT_TOPICParameterMaxTemp, maxTemps.c_str()); mqttClient.publish(MQTT_TOPICParameterMinTemp, minTemps.c_str()); mqttClient.publish(MQTT_TOPICParameterMaxHum, maxHums.c_str()); mqttClient.publish(MQTT_TOPICParameterMinLight, minLights.c_str()); mqttClient.publish(MQTT_TOPICParameterMinBv, minBodemvochts.c_str()); }

### 4.1.2.17. Loop functie

void loop() {
RFIDtagLezen();
waterReservoir();
mqttClient.loop();
}

### 4.2. Code RaspberryPi

Deze code zorgt alleen voor het kunnen gebruiken van een database en deze gebruiken om data te gaan visualiseren op Grafana.

### 4.2.1. Volledige code

Om de volledige code te zien, zie dan bestand ‘IoTproject.py’.

### 4.2.2. Code Uitgelegd

### 4.2.2.1. Libraries toevoegen

import re
from typing import NamedTuple import threading import paho.mqtt.client as mqtt from influxdb import InfluxDBClient from time import sleep

### 4.2.2.2. Variabelen om connectie aan te geven

first_connection_made = False

### 4.2.2.3. InfluxDB en MQTT instellingen

# InfluxDB instellingen

INFLUXDB_ADDRESS = 'localhost' INFLUXDB_USER = 'thibau'
INFLUXDB_PASSWORD = 'test' INFLUXDB_DATABASE = 'IoTproject'

# MQTT instellingen

MQTT_ADDRESS = 'localhost'
MQTT_USER = 'test'
MQTT_PASSWORD = 'test'
MQTT_TOPICWaarden = "serre/waarden/+"
MQTT_TOPICActuatoren = "serre/actuatoren/+" MQTT_TOPICParameters = "serre/parameters/+" MQTT_TOPICCommunication = "serre/communication/communication" MQTT_REGEX = "serre/([^/]+)/([^/]+)"
MQTT_CLIENT_ID = 'MQTTInfluxDBBridge'

influxdb_client = InfluxDBClient(INFLUXDB_ADDRESS, 8086, INFLUXDB_USER, INFLUXDB_PASSWORD, INFLUXDB_DATABASE)

previous_sensor_values = {}

### 4.2.2.4. Bepalen hoe MQTT berichten binnen komen

class SensorData(NamedTuple):
location: str
measurement: str
value: float

### 4.2.2.5. Functie om te verbinden met MQTT clients en subscriben op topics

def on_connect(client, userdata, flags, rc):
global first_connection_made
if not first_connection_made:
print('Connected with result code ' + str(rc)) first_connection_made = True client.subscribe(MQTT_TOPICWaarden) client.subscribe(MQTT_TOPICActuatoren) client.subscribe(MQTT_TOPICParameters)

### 4.2.2.6. Functie om te zien of de waarden die binnen komt een getal is

def _is_valid_number(value):
try:
float_value = float(value)
return not (float_value != float_value) # Checks for NaN except ValueError:
return False

### 4.2.2.7. Functie om berichten te parseren

def _parse_mqtt_message(topic, value): match = re.match(MQTT_REGEX, topic) if match:
location = match.group(1)
measurement = match.group(2) if measurement == 'status':
return None
if _is_valid_number(value):
return SensorData(location, measurement, float(value)) else:
return None

### 4.2.2.8. Functie om data door te sturen naar database

def _send_sensor_data_to_influxdb(sensor_data): json_body = [
{
'measurement': sensor_data.measurement, 'tags': {
'location': sensor_data.location },
'fields': {
'value': sensor_data.value
}
}
]
influxdb_client.write_points(json_body)

### 4.2.2.9. Functie om berichten terug te sturen via MQTT

def send_mqtt_signal(client, topic, message): client.publish(topic, message)

### 4.2.2.10. Functie om binnengekomen berichten af te handelen

def on_message(client, userdata, msg):
print(msg.topic + ' ' + str(msg.payload))
sensor_data = _parse_mqtt_message(msg.topic, msg.payload.decode('utf-8'))
if sensor_data is not None: _send_sensor_data_to_influxdb(sensor_data) send_mqtt_signal(client, MQTT_TOPICCommunication, "hallo")

### 4.2.2.11. Functie om te bepalen naar welke database de data moet worden

gestuurd

def _init_influxdb_database():
databases = influxdb_client.get_list_database()
if len(list(filter(lambda x: x['name'] == INFLUXDB_DATABASE, databases))) == 0:
influxdb_client.create_database(INFLUXDB_DATABASE) influxdb_client.switch_database(INFLUXDB_DATABASE)

### 4.2.2.12. MQTT-loop functie

def mqtt_loop():
mqtt_client =
mqtt.Client(mqtt.CallbackAPIVersion.VERSION1,MQTT_CLIENT_ID) mqtt_client.username_pw_set(MQTT_USER, MQTT_PASSWORD) mqtt_client.on_connect = on_connect mqtt_client.on_message = on_message print("-------------------------")

mqtt_client.connect(MQTT_ADDRESS, 1883) mqtt_client.loop_forever()

### 4.2.2.13. Main functie

def main():
_init_influxdb_database()

mqtt_thread = threading.Thread(target=mqtt_loop) mqtt_thread.daemon = True
mqtt_thread.start()

while True:
try:
sleep(1)
except KeyboardInterrupt:
print("Program stopped by user") break

### 4.2.2.14. Hoofd functie

if __name__ == '__main__': print('MQTT to InfluxDB bridge') main()

# 5. Grafana Server

### 5.1. MQTT communicatie

### 5.1.1. Mosquitto installeren

Om MQTT communicatie mogelijk te maken moet je eerst ‘mosquitto’ installeren. Dit doe je zo:
- sudo apt-get update
- sudo apt-get install mosquitto mosquitto-clients
- sudo systemctl start mosquitto
- sudo systemctl enable mosquitto

### 5.1.2. Configuratie bestand aanpassen

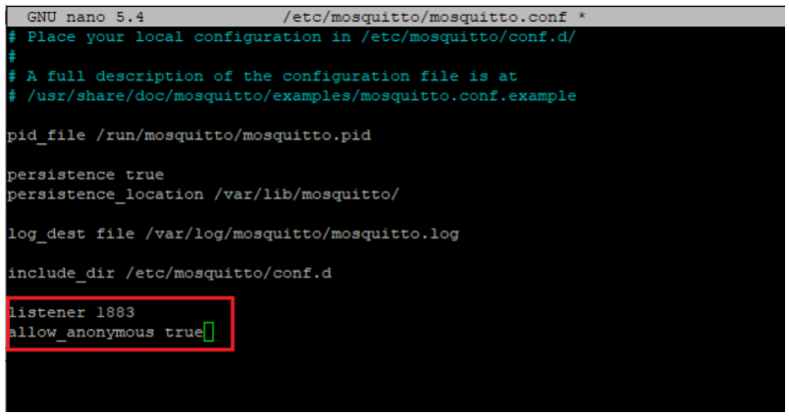
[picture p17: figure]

- Listener op “1883” zetten
- Allow_anonymous “true” zetten

### 5.1.3. Code maken en kijken of de communicatie goed gebeurt

Hierbij een voorbeeld van hoe de geslaagde communicatie er uit kan zien:

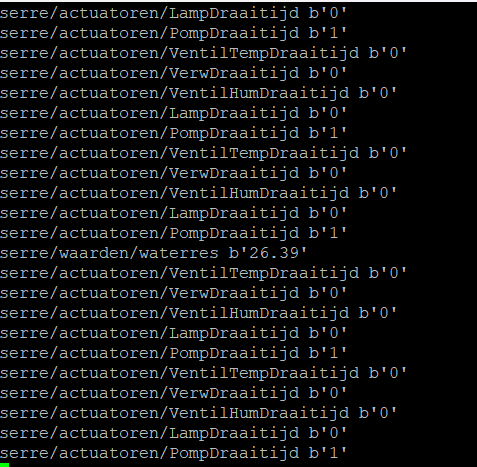
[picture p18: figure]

Je ziet hierbij de topics waarop er ontvangen wordt en wat er ontvangen wordt. Zie ‘Code’ om te zien hoe je deze communicatie kunt laten lukken

### 5.2. Server Setup

Om de server te laten werken moet je ook een InfluxDB database aanmaken dat doe je op deze manier.

### 5.2.1. Installeer InfluxDB

InfluxDB installeren doe je met deze commando’s:
- sudo apt-get update
- sudo apt-get install influxdb
- sudo systemctl start influxdb
- sudo systemctl enable influxdb

### 5.2.2. Maak een database aan

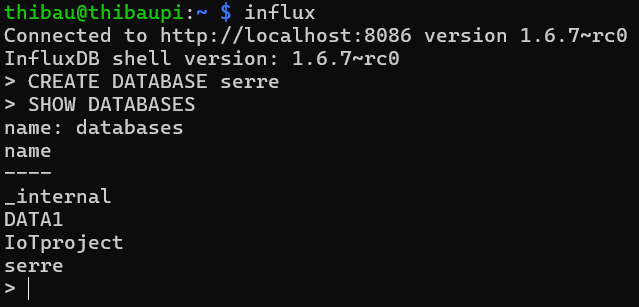
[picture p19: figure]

Een database aan maken in InfluxDB om je data te kunnen opslaan doe je op deze manier:

### 5.2.3. Controleer of de data aankomt in de database

Controleren of de data aankomt in je database doe je zo:

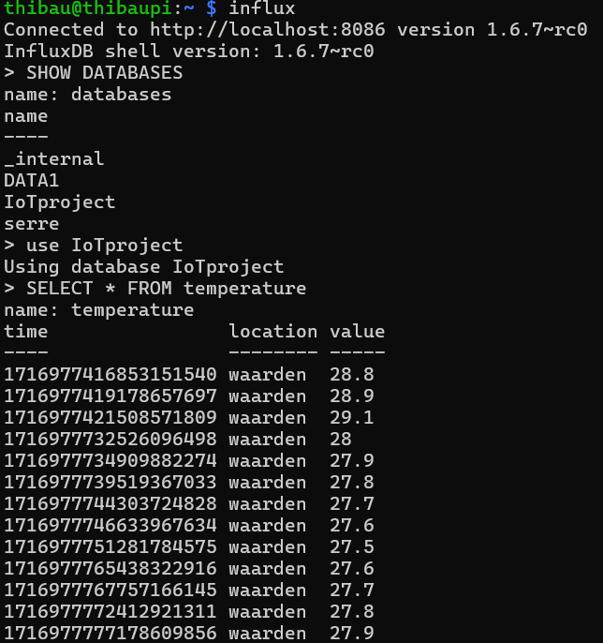
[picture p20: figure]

(Ik heb nu de database ‘IoTproject’ gebruikt en niet ‘serre’ omdat alle data van mijn project daar aankomen. De ‘serre’ database was gewoon een voorbeeld van hoe je een database moet aanmaken.)

### 5.3. InfluxDB connecteren met Grafana voor visualisatie

Om de data te visualiseren moet je je InfluxDB database koppelen aan je Grafana server. Dit doe je zo.

### 5.3.1. Zoek je Grafana server

Om op je Grafana server te geraken moet je gewoon in de zoekbalk van je browser het IP-adres in typen van je RaspberryPi met ‘:3000’ er achteraan.

### 5.3.2. Log in in Grafana

Om in te loggen in Grafana wordt er gevraagd naar een wachtwoord en gebruikers naam. Deze zijn standaard ‘admin’ en ‘admin’. Je kan deze aanpassen.

### 5.3.3. Maak een connectie met je InfluxDB database

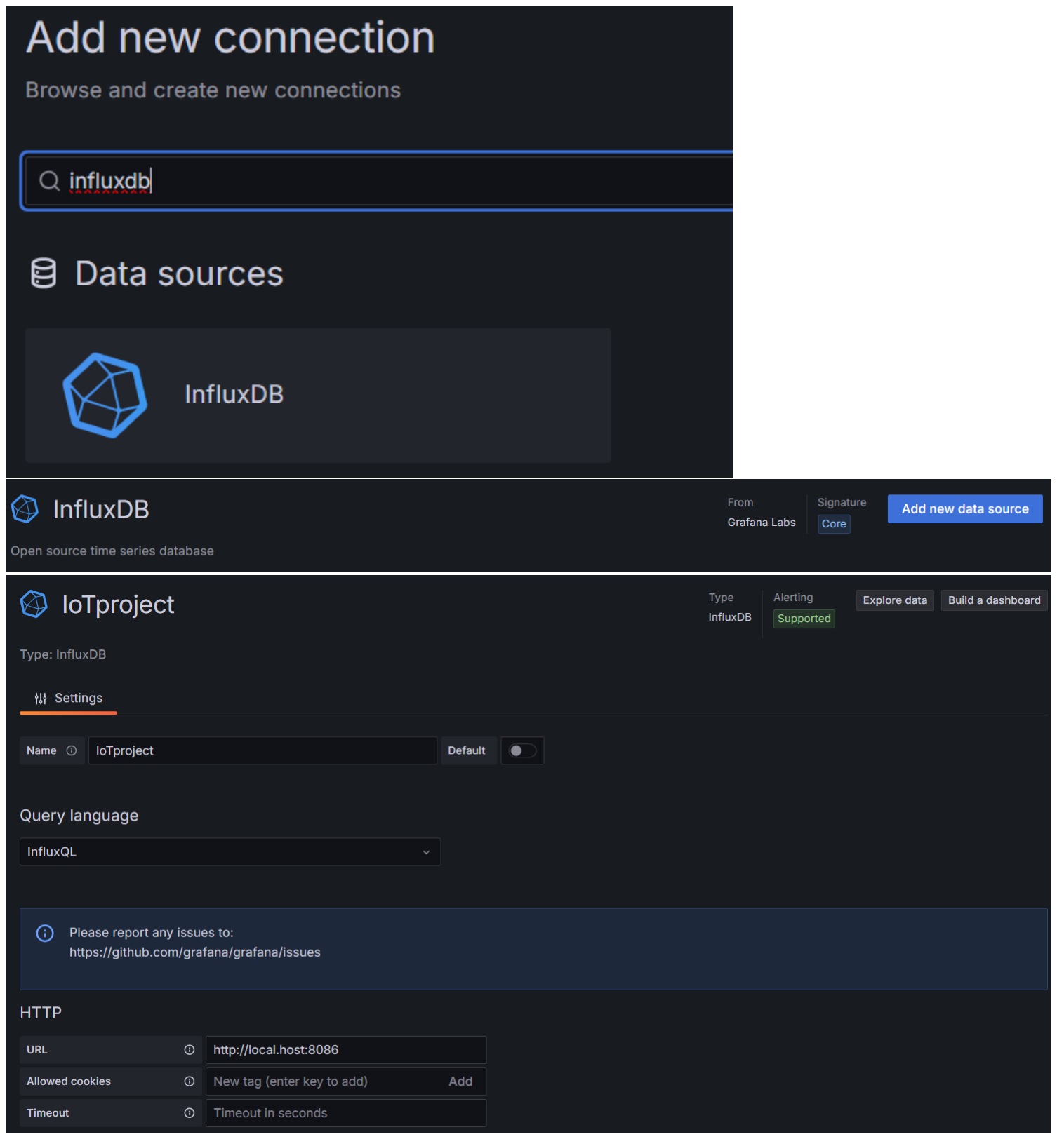
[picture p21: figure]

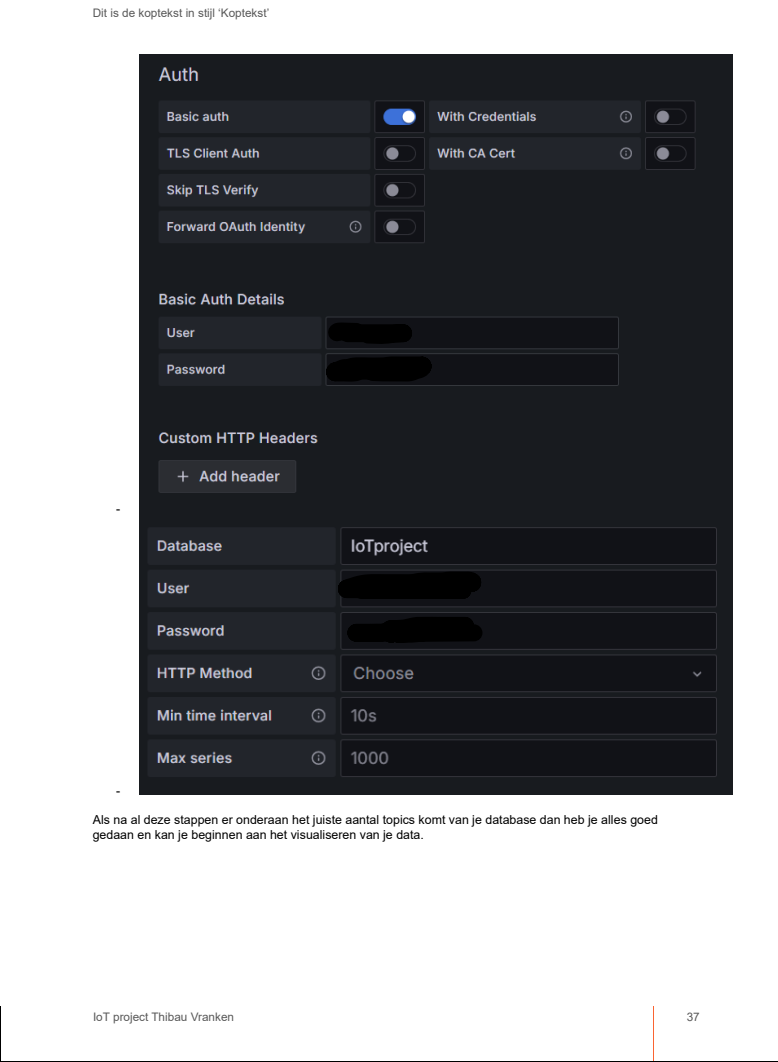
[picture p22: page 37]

Als na al deze stappen er onderaan het juiste aantal topics komt van je database dan heb je alles goed
gedaan en kan je beginnen aan het visualiseren van je data.

### 5.4. Data Visualisatie

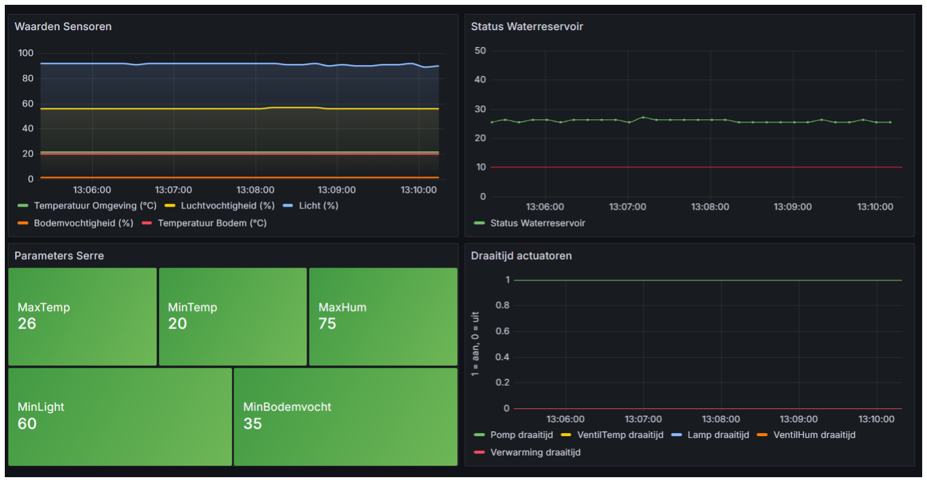
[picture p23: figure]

Zo ziet mijn dashboard eruit van de serre. Hier worden de sensor waarden, draaitijd van alle actuatoren en de ingestelde parameters op een mooie en overzichtelijke manier voorgesteld.
(Alles wijst zichzelf uit qua visualiseren van je data. Kijk wat rond op de site en je zult zelf zien wat je allemaal kan doen.)

# 6. Datasheets

### 6.1. ESP 32

https://www.espressif.com/sites/default/files/documentation/esp32_datasheet_en.pdf

### 6.2. RaspberryPi

https://datasheets.raspberrypi.com/rpi4/raspberry-pi-4-datasheet.pdf

### 6.3. BC547B Transistor

https://cdn-reichelt.de/documents/datenblatt/A100/BC546_48-CDIL.pdf

### 6.4. PC 817 optocoupler

https://cdn-reichelt.de/documents/datenblatt/A500/PC817XXNSZ1B_07OCT16_SPEC_ED-16P010.pdf

### 6.5. 5V relay

https://www.circuitbasics.com/wp-content/uploads/2015/11/SRD-05VDC-SL-C-Datasheet.pdf

### 6.6. Feedback LED’s

https://cdn-reichelt.de/documents/datenblatt/A500/NSPR510GS-E(2047).pdf

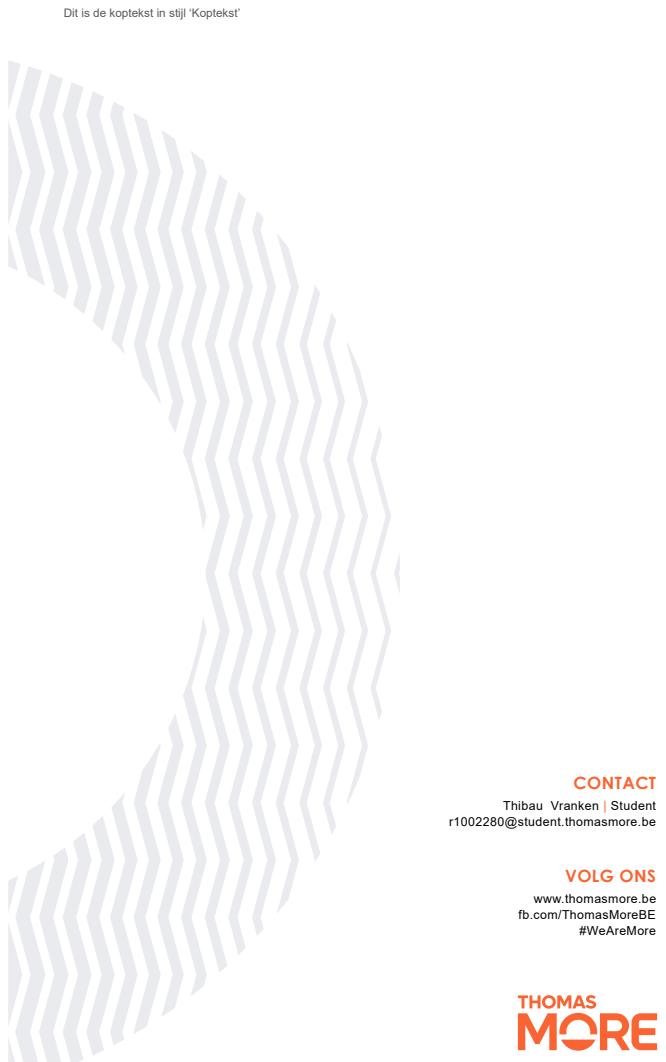
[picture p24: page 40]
CONTACT; VOLG ONS; #WeAreMore

Thibau Vranken | Student

r1002280@student.thomasmore.be

www.thomasmore.be
fb.com/ThomasMoreBE

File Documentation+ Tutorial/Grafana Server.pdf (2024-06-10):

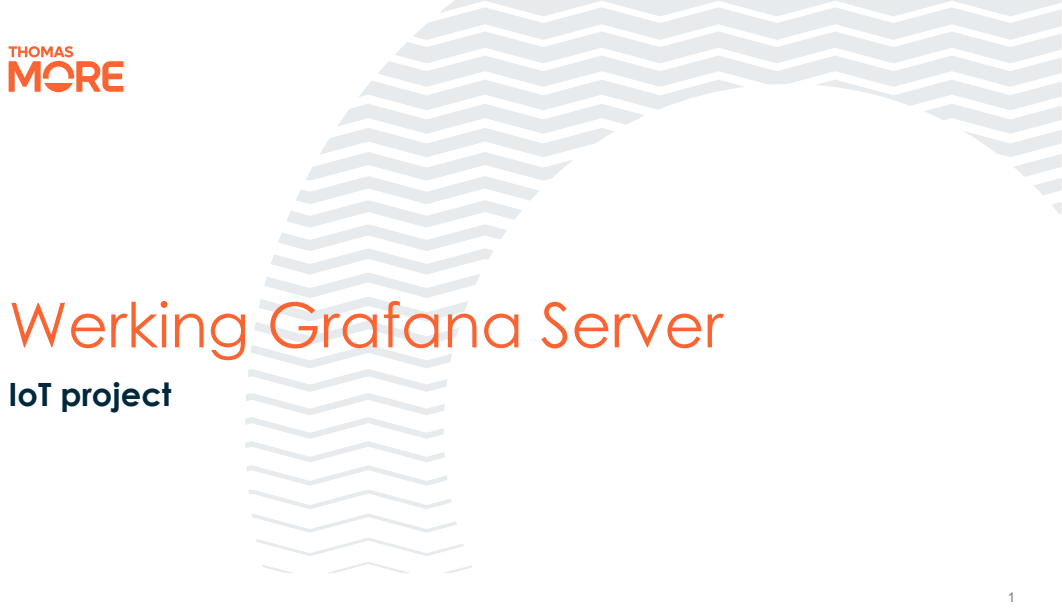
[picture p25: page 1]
IoT project

Werking Grafana Server

# Inhoud

- Opzet Server
- Werking MQTT
- Visualisatie Grafana
- Uitdagingen en Oplossingen

# Opzet Server

- Duidelijkheid over situatie serre
- Kijken of de planten goed verzorgd geweest zijn
- Industrieel -> kijk om kosten te besparen waar mogelijk
- Van op afstand -> toegankelijker

# Werking MQTT

- MQTT installeren op RaspberryPi en MQTT library installeren op ESP32

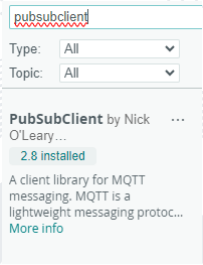
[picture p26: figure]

# Werking MQTT

- Configuratie bestanden aanpassen

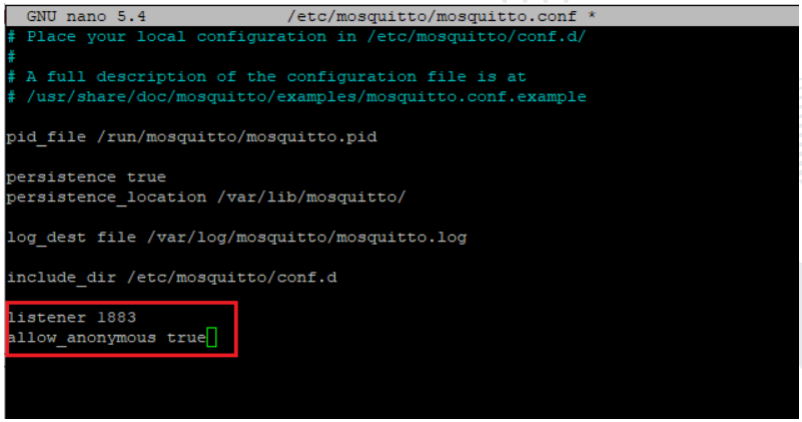
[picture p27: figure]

# Werking MQTT

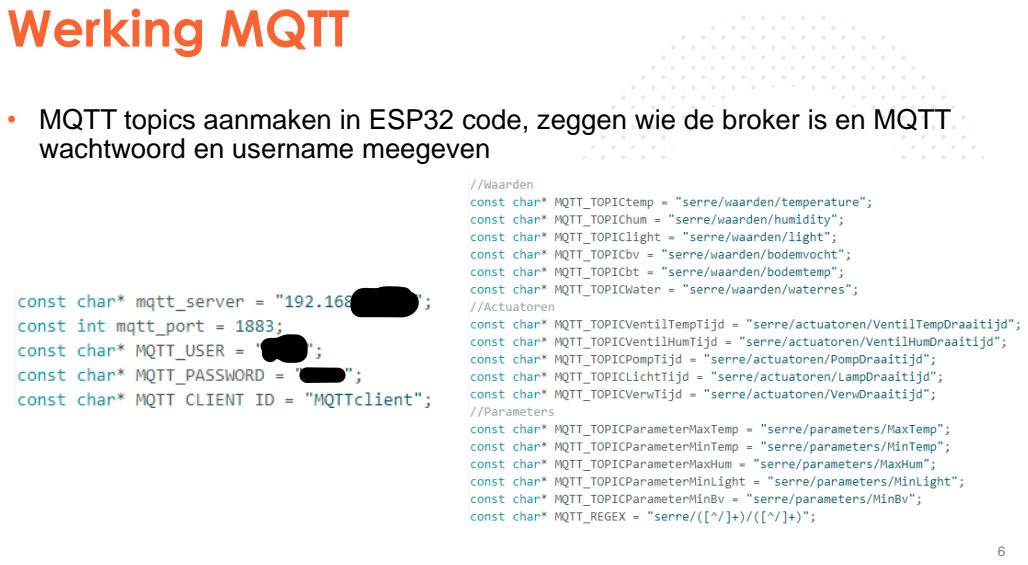
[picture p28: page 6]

• MQTT topics aanmaken in ESP32 code, zeggen wie de broker is en MQTT
wachtwoord en username meegeven

# Werking MQTT

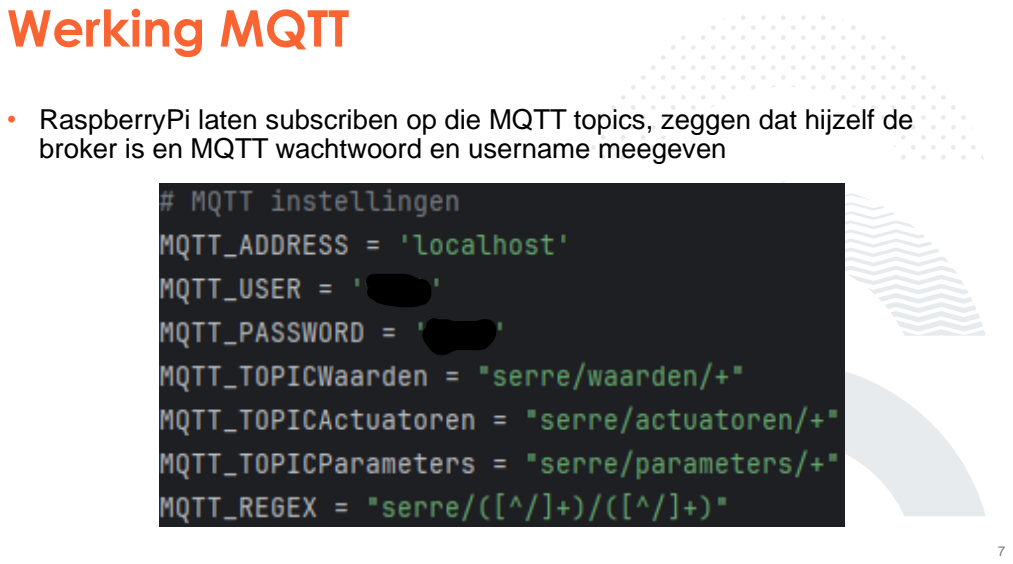
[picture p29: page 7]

• RaspberryPi laten subscriben op die MQTT topics, zeggen dat hijzelf de
broker is en MQTT wachtwoord en username meegeven

# Werking MQTT

- Gegevens doorsturen via de topic’s naar de broker

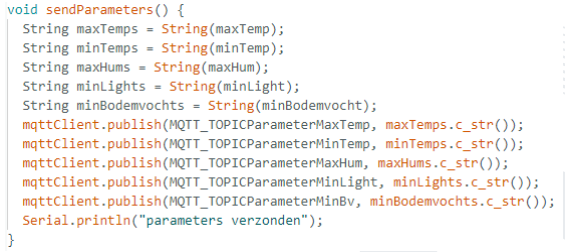
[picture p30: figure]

# Werking MQTT

- Gegevens ontvangen op de geabonneerde topic’s

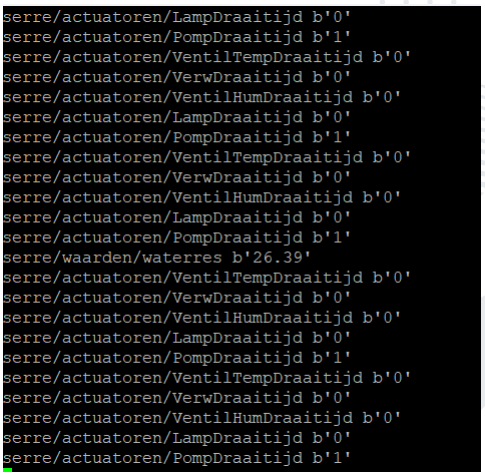
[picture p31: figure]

# Grafana Visualisatie

- Data sturen naar database (InfluxDB)
- Via webserver naar Grafana server gaan
- IP adres van broker opzoeken via poort 3000 (192.168….:3000)
- Inloggen standaard “admin” “admin”

# Grafana Visualisatie

- Database connecteren met Grafana

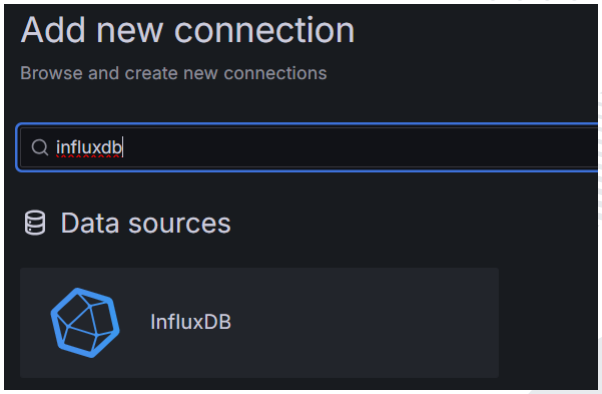
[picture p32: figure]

# Grafana Visualisatie

- Database connecteren met Grafana

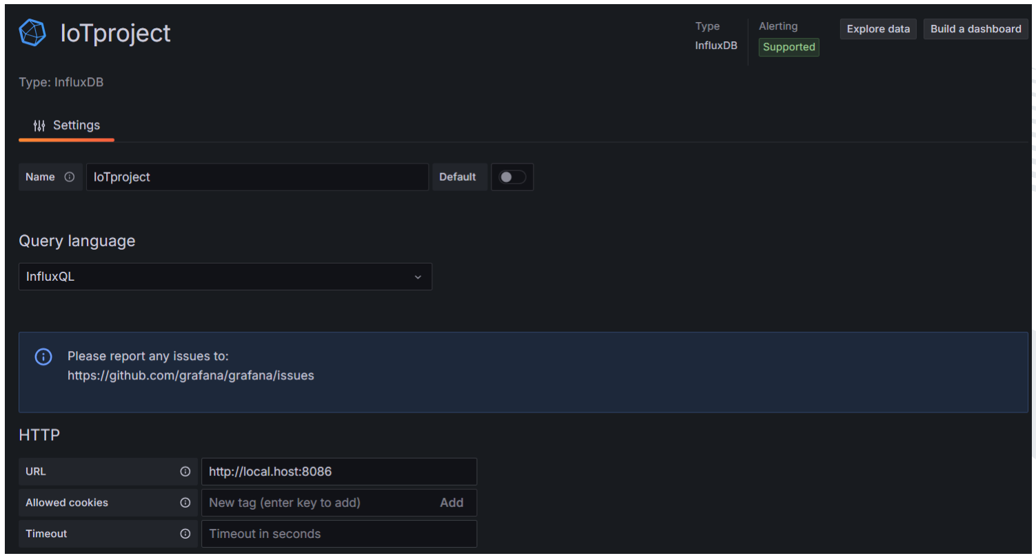
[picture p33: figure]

# Grafana Visualisatie

- Database connecteren met Grafana

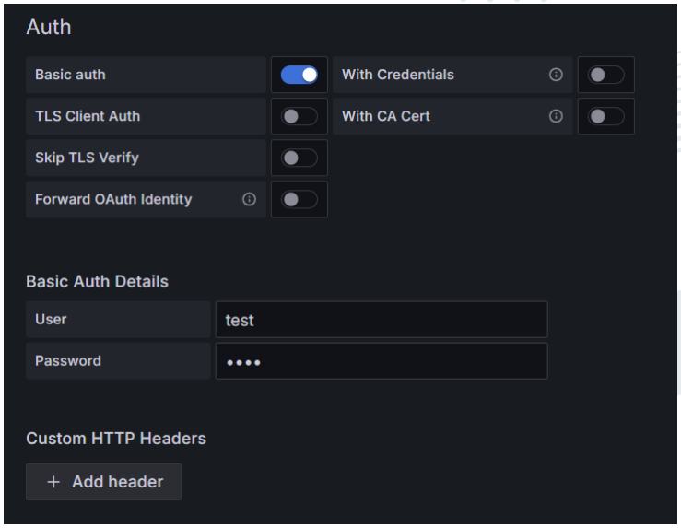
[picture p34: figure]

# Werking MQTT

- Gegevens ontvangen op de geabonneerde topic’s

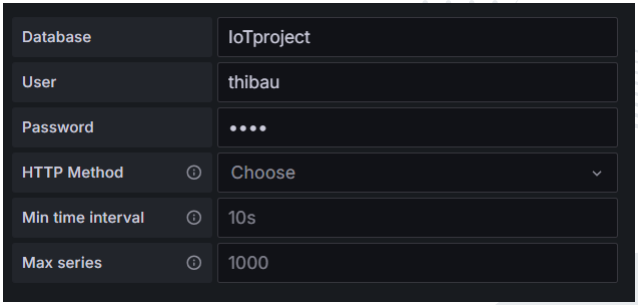
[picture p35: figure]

- Als alles goed is komt het aantal topics van je database tevoorschijn en kan je beginnen aan je visualisaties

# Visualisaties Grafana

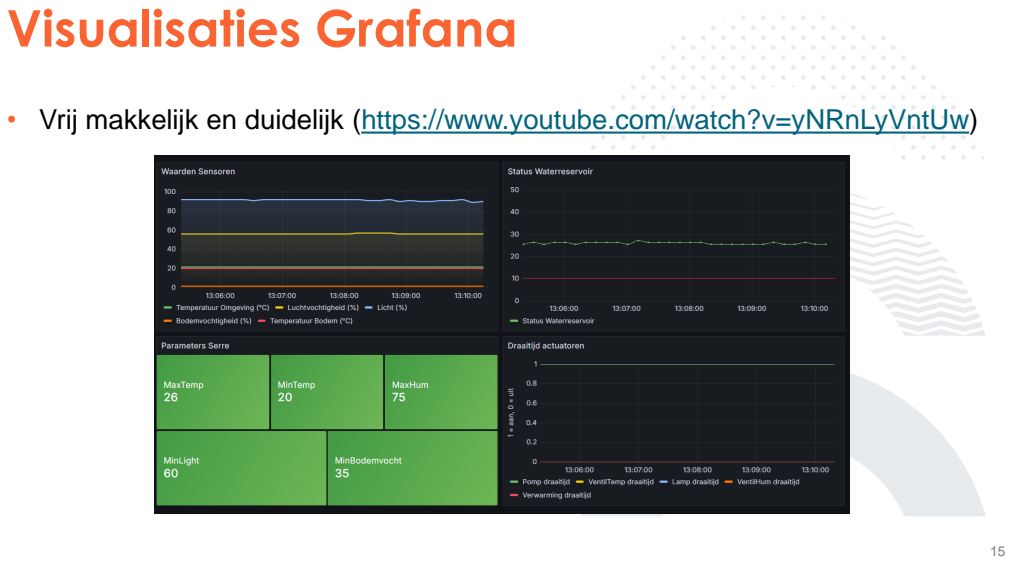
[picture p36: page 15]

• Vrij makkelijk en duidelijk (https://www.youtube.com/watch?v=yNRnLyVntUw)

# Uitdagingen en Oplossingen

- Alles moet exact hetzelfde zijn
- Kleine typ fout en de communicatie kan volledig vastlopen

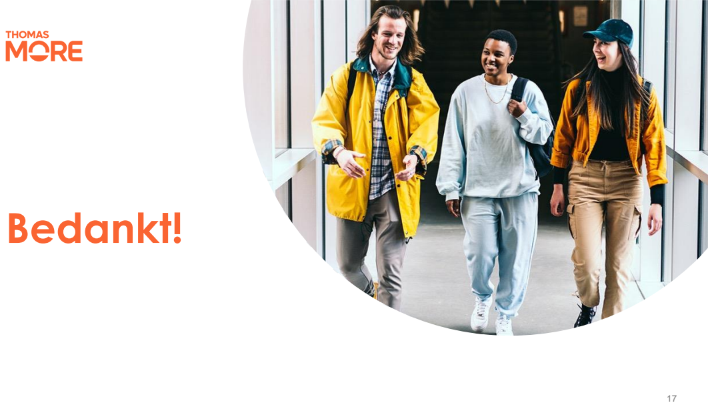
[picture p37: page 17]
Bedankt!

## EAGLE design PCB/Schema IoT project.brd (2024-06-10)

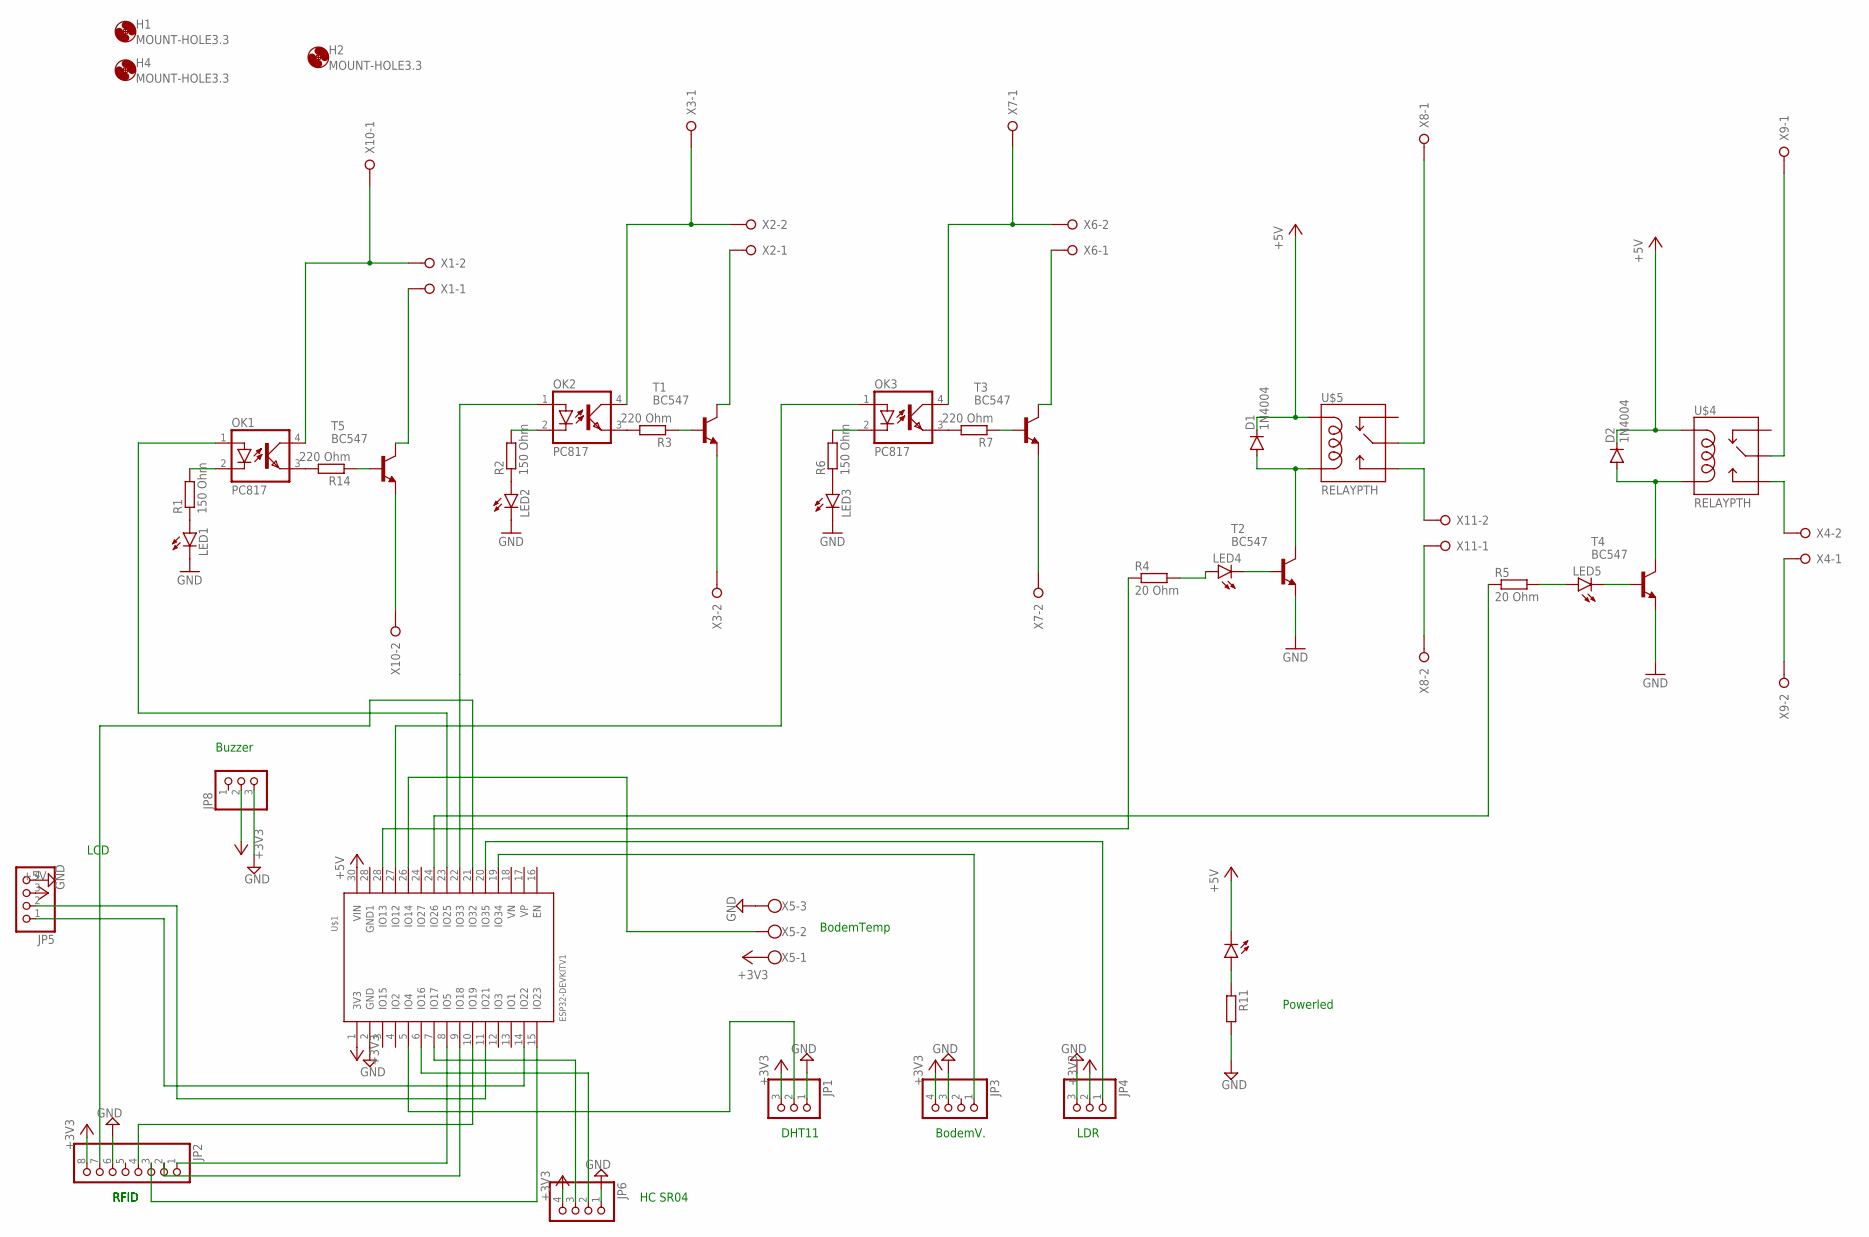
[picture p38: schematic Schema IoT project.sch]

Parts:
D1, D2: 1N4004; DO41-10
H1, H2, H4: MOUNT-HOLE3.3; 3,3
JP1, JP4, JP8: PINHD-1X3; 1X03
JP2: PINHD-1X8; 1X08
JP3, JP5, JP6: PINHD-1X4; 1X04
LED1, LED2, LED3, LED4, LED5: LED5MM
OK1, OK2, OK3: PC817; DIL04
PWRLEDRASPBERRYPI2: LED5MM
R1, R2, R6: 150 Ohm; 0207/10
R3, R7, R14: 220 Ohm; 0207/10
R4, R5: 20 Ohm; 0207/10
R11: R-EU_0207/10; 0207/10
T1, T2, T3, T4, T5: BC547; TO92
U$1: ESP32DEVKITV1; ESP32-DEVKITV1
U$4, U$5: RELAYPTH; SRD-05VDC-SL-C
X1, X2, X3, X4, X6, X7, X8, X9, X10, X11: W237-02P; W237-132
X5: W237-103

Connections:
+3V3: JP1.3, JP2.8, JP3.4, JP4.2, JP6.4, JP8.2, U$1.1 (3V3), X5.1
+5V: D1.C, D2.C, JP5.3, PWRLEDRASPBERRYPI2.K (C), U$1.30 (VIN), U$4.COIL1, U$5.COIL1
GND: JP1.1, JP2.6, JP3.3, JP4.3, JP5.4, JP6.1, JP8.3, LED1.K (C), LED2.K (C), LED3.K (C), R11.2, T2.1 (E), T4.1 (E), U$1.2 (GND), X5.3
unnamed: OK1.4 (COL), X1.2, X10.1
unnamed: LED2.A, R2.1
unnamed: D1.A, T2.3 (C), U$5.COIL0
unnamed: OK2.4 (COL), X2.2, X3.1
unnamed: OK1.3 (EMIT), R14.2
unnamed: OK2.3 (EMIT), R3.2
unnamed: R3.1, T1.2 (B)
unnamed: T1.3 (C), X2.1
unnamed: D2.A, T4.3 (C), U$4.COIL0
unnamed: JP3.1, U$1.19 (IO34)
unnamed: LED1.A, R1.1
unnamed: R14.1, T5.2 (B)
unnamed: T1.1 (E), X3.2
unnamed: PWRLEDRASPBERRYPI2.A, R11.1
unnamed: OK2.2 (C), R2.2
unnamed: T5.3 (C), X1.1
unnamed: LED4.K (C), T2.2 (B)
unnamed: R5.1, U$1.24 (IO27)
unnamed: LED4.A, R4.2
unnamed: T5.1 (E), X10.2
unnamed: JP5.2, U$1.11 (IO21)
unnamed: LED3.A, R6.1
unnamed: OK3.1 (A), U$1.27 (IO12)
unnamed: U$4.SWCOMMON, X9.1
unnamed: U$5.SWCOMMON, X8.1
unnamed: OK1.2 (C), R1.2
unnamed: R4.1, U$1.28 (IO13)
unnamed: OK3.4 (COL), X6.2, X7.1
unnamed: OK3.3 (EMIT), R7.2
unnamed: X8.2, X11.1
unnamed: U$1.26 (IO14), X5.2
unnamed: JP6.3, U$1.7 (IO17)
unnamed: JP4.1, U$1.20 (IO35)
unnamed: JP2.7, U$1.21 (IO32)
unnamed: JP2.4, U$1.10 (IO19)
unnamed: JP6.2, U$1.6 (IO16)
unnamed: R7.1, T3.2 (B)
unnamed: JP1.2, U$1.5 (IO4)
unnamed: JP5.1, U$1.14 (IO22)
unnamed: T3.3 (C), X6.1
unnamed: U$5.SWOPEN, X11.2
unnamed: U$4.SWOPEN, X4.2
unnamed: T3.1 (E), X7.2
unnamed: OK3.2 (C), R6.2
unnamed: X4.1, X9.2
unnamed: LED5.A, R5.2
unnamed: LED5.K (C), T4.2 (B)
unnamed: JP2.3, U$1.15 (IO23)
unnamed: JP2.2, U$1.9 (IO18)
unnamed: JP2.1, U$1.8 (IO5)
unnamed: OK1.1 (A), U$1.23 (IO25)

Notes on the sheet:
DHT11
BodemV.
LDR
BodemTemp
RFID
HC SR04
LCD
Powerled
Buzzer

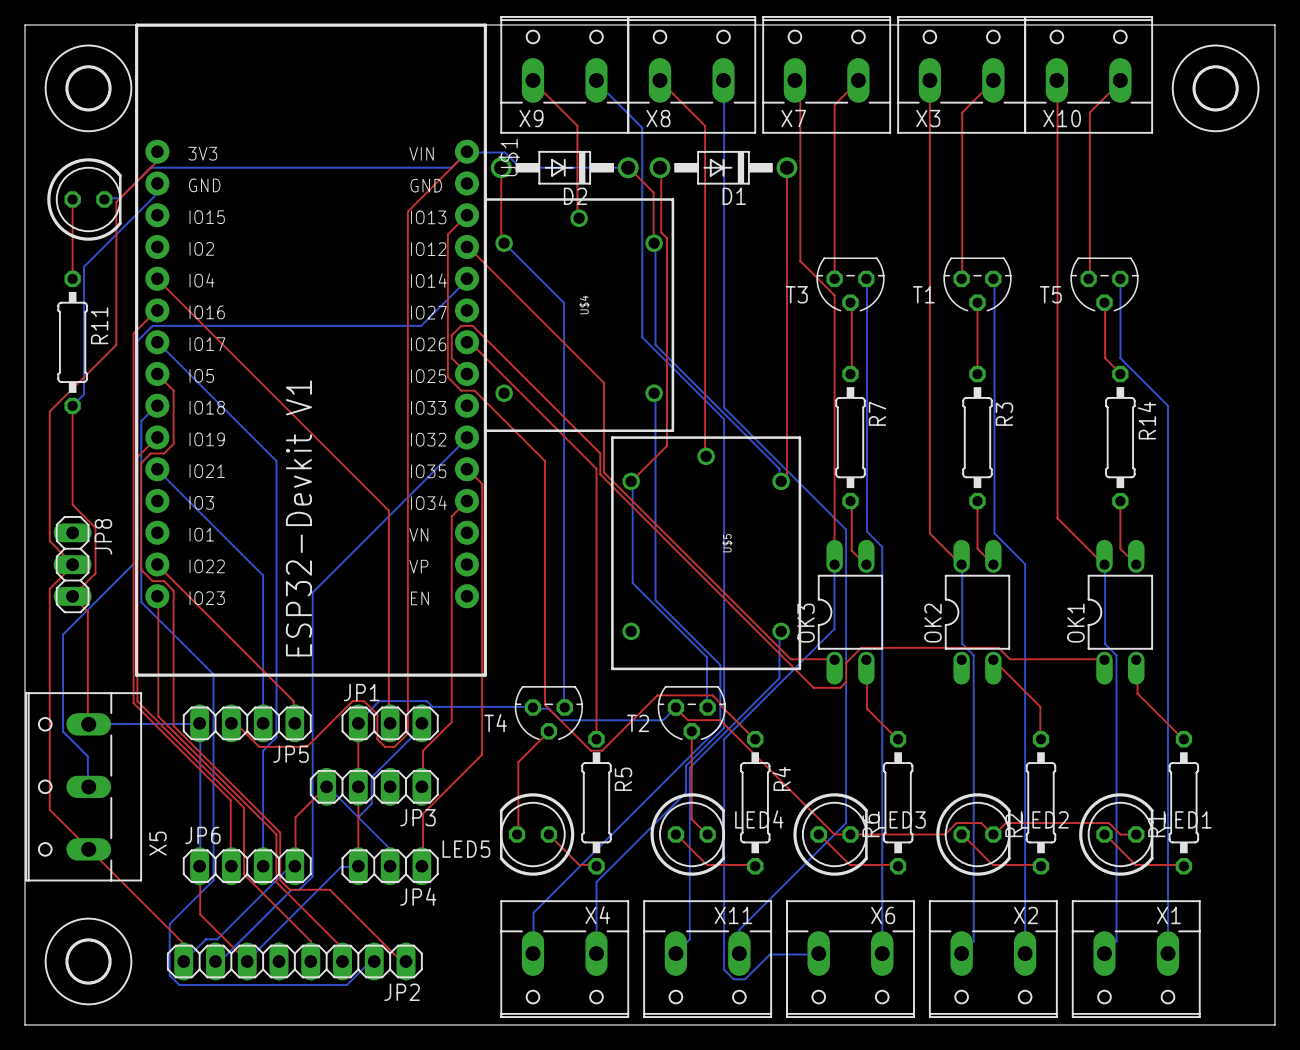
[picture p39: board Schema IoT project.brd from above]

Board: 2 copper layers, 100.0 x 80.0 mm, 49 parts (0 on the bottom side), 54 nets.
